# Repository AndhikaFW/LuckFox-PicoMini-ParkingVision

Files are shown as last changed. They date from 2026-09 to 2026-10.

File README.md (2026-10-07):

# LuckFox-PicoMini-ParkingVision

A distributed smart parking monitoring vision system utilizing **LuckFox Pico Mini** AI camera boards paired with **ESP32-S3 RAP** nodes, chained together and bridged to a Raspberry Pi 4 backend over wired Ethernet.

Every node in this project is a **parking lot** -- there is no separate entrance/gate node yet (may be added later as its own thing).

---

## System Components (per node)

Each parking-lot node is one **LuckFox Pico Mini** + one **ESP32-S3**, wired together over SPI:

1. **LuckFox Pico Mini (RV1103) -- on-device vision AI**
   - Reads a camera feed, encodes/splits it into **3x 600x400 video streams**.
   - Pipeline per stream: motion detection -> AI car detection -> sleep briefly -> occupancy check (vacant/occupied) -> if occupied, crop + OCR the plate.
   - Sends the 3 encoded video streams and, if present, the cropped plate result to its paired ESP32-S3.

2. **ESP32-S3 RAP (chain relay + one Gateway uplink)**
   - Runs the exact same firmware on every unit (see [`src/ESP32-S3-RAP`](src/ESP32-S3-RAP)); role and chain position come from a small per-unit provisioning step, not a separate build.
   - One designated node (`node_id == 0`, the **Gateway**) also carries a **W5500** module and bridges to the Raspberry Pi 4 backend over a direct Ethernet cable (RJ45) -- it's still a parking-lot node like any other, just the one with this extra uplink role.

---

## Network Architecture: Chain (not a closed ring)

Despite the "RAP" (Ring Access Protocol) name -- kept from this project's original design for naming continuity (`ring_size`, `node_id`, etc. still appear throughout) -- the topology is a **one-way chain**, not a closed loop: there's no "first" node and the Gateway has no outgoing link back into the chain, it only sinks data out to the RPi4.

Every node has its own initiative: it originates its own occupancy/plate reading and video frames on its own schedule, and relays whatever it receives from its upstream neighbor (`prev`) toward its downstream neighbor (`next`) -- both interleaved through the same per-hop link. Two independent transports run in parallel over the same radio:

- **ESP-NOW** -- small `StatusPacket`s (`origin_node_id`, `seq`, `occupied`, `plate`), hop-by-hop with stop-and-wait flow control (a node only accepts a new packet from `prev` once it has room to forward it to `next`).
- **WiFi AP+STA daisy-chain (TCP)** -- bulk video, since raw frames are far too large for ESP-NOW's 250-byte limit. Each frame carries `{origin_node_id, stream_id, seq, data_len}` so its source lot and camera are always identifiable, even after several relay hops.

```mermaid
graph LR
    subgraph "Chain Network (one-way, no closing loop)"
        Node1["Lot 1<br>(LuckFox + ESP32-S3)"] -->|"status/plate + video"| Node2["Lot 2<br>(LuckFox + ESP32-S3)"]
        Node2 -->|"status/plate + video"| Node3["Lot 3<br>(LuckFox + ESP32-S3)"]
        Node3 -->|"status/plate + video"| NodeN["... Lot N-1"]
        NodeN -->|"status/plate + video"| Gateway["Lot 0 / GATEWAY<br>(LuckFox + ESP32-S3 + W5500)"]
    end

    Gateway -->|"RJ45 (W5500), status:5000 video:5300"| RPi["Raspberry Pi 4 backend"]
```

### Why a chain instead of a mesh/star

- **Deterministic, low-collision flow**: every hop is a simple point-to-point link (ESP-NOW unicast + a WiFi AP/STA pair), so there's no contention/arbitration between nodes for a shared medium.
- **Backpressure, not packet loss**: per-hop stop-and-wait means a slow/busy hop naturally throttles the whole chain instead of dropping data silently.
- **Simple cabling-free daisy-chaining**: adding a lot just means provisioning one more node with the next `node_id`; no rewiring of a shared bus or router needed.

Self-healing/re-routing around a permanently dead node is **not** implemented yet -- see `docs/network/topology.md` in the submodule for the full list of current limitations.

---

## Data reaching the backend

Both channels tag every reading/frame with `origin_node_id`, so the Raspberry Pi 4 backend can always tell which lot (and, for video, which of its 3 cameras) a piece of data came from:

| Channel | Port | Content |
| :--- | :--- | :--- |
| Status/plate | 5000 | One line per reading: `node_id:occupied:plate` |
| Video | 5300 | Binary, one frame per message: `{origin_node_id, stream_id, seq, data_len}` + raw frame bytes |

Naming a lot (e.g. "Lot A0") is a Raspberry Pi-side concern, not firmware: see [`backend/node_names.json`](backend/node_names.json) and the demo listener scripts in the same folder (`status_listener.py`, `video_listener.py`), which resolve `node_id -> name` and prove data is separable/displayable per lot. This `backend/` folder is plain Python living directly in this repo (not the ESP32 firmware submodule, and not a submodule itself) -- it's Raspberry Pi-side code, kept separate from the ESP32-S3 firmware.

---

## Getting Started

### Cloning the Repository
```bash
git clone --recurse-submodules https://github.com/AndhikaFW/LuckFox-PicoMini-ParkingVision.git
```

If already cloned without submodules:
```bash
git submodule update --init --recursive
```

### Layout

- [`src/ESP32-S3-RAP`](src/ESP32-S3-RAP) -- ESP32-S3 firmware **only** (its own git submodule/repo). Build/flash/provisioning instructions and the full protocol/topology write-up live there: [`docs/network/topology.md`](src/ESP32-S3-RAP/docs/network/topology.md).
- [`backend/`](backend) -- Raspberry Pi 4-side Python (demo listeners + `node_names.json`). Plain files in this repo, not inside the firmware submodule and not a submodule of its own -- there's nothing here that needs its own version history separate from the rest of this repo.

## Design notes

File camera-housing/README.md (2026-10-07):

# Camera body + manual pan/tilt hinge (per parking-lot node)

One integrated camera body (LuckFox RAP Shield PCB + SC3336 module both INSIDE it) on a
manual 2-axis (pan + tilt) hinge, futuristic-minimalist styling. Four scripts:

- **`build_housing.py`** -- flat `Base` + `Standoffs` (a plain, non-pivoting PCB mounting
  plate). No longer used by the camera design below; kept because it's still a valid,
  independently-printable option if a flat non-pivoting mount is ever wanted, and because
  `camera_casing.py` imports the PCB/SC3336 dimension constants from it.
- **`camera_casing.py`** -- the actual camera design: `CeilingMount` (fixed) +
  `ComponentBox` (round, ROTATING turret -- placeholder enclosure for a future buck
  converter + W5500 module, also carries the pan/tilt arms) + `CameraBody` (the shell, PCB
  + SC3336 both inside, square-cross-section tube) + `BackCover` (removable, for
  PCB/heatsink access).
- **`assemble_pcb.py`** -- adds the real PCB (STEP import) onto `build_housing.py`'s Base,
  into `camera_housing.FCStd`. Only relevant if that flat mount is actually used.
- **`full_assembly.py`** -- combines `camera_casing.py`'s parts with the real PCB (STEP
  import, positioned inside `CameraBody`) into one `full_assembly.FCStd`.
- **`render_hero.py`** -- renders a genuine angled 3D shot (`hero_render.png`) from
  `full_assembly.FCStd`, working around the offscreen top-down-only bug the older render
  scripts hit (see "Regenerating everything" below for the actual root cause found).

## Regenerating everything

```bash
cd camera-housing
QT_QPA_PLATFORM=offscreen ~/Downloads/FreeCAD-1.1.3.AppImage --console <<'EOF'
exec(open('camera_casing.py').read())
EOF
QT_QPA_PLATFORM=offscreen ~/Downloads/FreeCAD-1.1.3.AppImage --console <<'EOF'
exec(open('full_assembly.py').read())
EOF
```
(`build_housing.py`/`assemble_pcb.py` only needed if you also want the standalone flat
mount -- see their own section below.)

The older renders (`render_casing.py`, `render_full.py`, `render_screenshot.py`) each
produce a `.png` from their matching `.FCStd`, but all render a straight-down top view
regardless of the `viewIsometric()` call in the script. **Root cause found**: inspecting
`view.getCamera()` right after `viewIsometric()` shows the camera's orientation is left at
identity (axis-angle `angle=0`) in this offscreen setup -- `viewIsometric()` silently fails
to actually rotate the camera here, even though it doesn't raise an error. `render_hero.py`
works around this by building and setting a real camera string directly (`view.setCamera(...)`
with a manually-computed non-identity orientation) instead of relying on `viewIsometric()`
-- confirmed via `getCamera()` showing a proper non-zero angle afterward, and the resulting
image actually being a real angled view, not another flat top-down one. Geometry
correctness in this project is still verified via real bounding-box/circle-center/
boolean-overlap queries first and foremost (see each section below for what was actually
checked) -- `render_hero.py` is for producing an actual presentable image, not for
verification.

(`--console camera_casing.py` as a direct CLI arg does *not* auto-run it in FreeCAD 1.1.3
-- pipe the `exec(...)` line into stdin as shown, or open the files as macros from the GUI.)

---

## The camera design (`camera_casing.py` + `full_assembly.py`)

### Why the PCB moved inside

Earlier revisions kept the PCB on a separate flat `Base`, cabled to a small external
camera head, specifically so heatsink work on the LuckFox Pico Mini never had to touch
the pan/tilt mechanics. On request, the PCB now lives inside `CameraBody` instead -- one
integrated unit, no external FPC run. Heatsink/PCB access is still separable: remove only
`BackCover` (a few M3 self-tap screws), the rest of the rig stays untouched.

### Hardware: M5 wing bolt (pan + left tilt), M4 set-screw (right tilt only)

M5 bumped up from M4 (used in the small SC3336-only version) now that the body is much
bigger/heavier -- it holds the full PCB, not just a 20x20mm sensor board. Only the right
tilt pivot uses an M4 self-tap set-screw instead of a wing bolt, since that's the only
bore that has to stay open end-to-end for the cable (see "Cable path" below) -- the pan
pivot is a plain M5 bolt like the left tilt one. Confirmed real, commonly stocked
(searched on Tokopedia, not guessed): "WING NUT M4 M5 M6 M8 M10 ... MUR KUPING MUR KUPU
KUPU" lists M4/M5 together.

### Assembly stack

**ComponentBox is now a round, ROTATING turret** (on request: "rubah kotak diatas kamera
... menjadi tabung bundar supaya dapat berputar"), replacing the old MountPlate<->PanPlate
pivot pair. Before implementing, the ambiguity in "supaya dapat berputar" (just reshape it
into a cylinder while keeping it fixed, vs. make ComponentBox itself the rotating part) was
checked directly with the user -- confirmed: ComponentBox itself rotates. This merges what
used to be three parts (a fixed square ComponentBox holding electronics + a fixed
MountPlate lid + a rotating PanPlate holding the arms) into two:

1. **CeilingMount** -- NEW, FIXED, sits at the bottom of the stack (wherever this gets
   mounted -- wall, pole, an off-the-shelf adjustable CCTV bracket, confirmed real listings
   exist, e.g. "Adjustable Bracket Tiang Kamera CCTV" on Tokopedia). Takes over MountPlate's
   old role but simpler: a plain M5 pan-pivot hole + 4 corner mounting holes, nothing else
   -- **no cable hole anymore** (the electronics moved onto the rotating ComponentBox
   itself, see "Cable path" below).
2. **ComponentBox** -- now a round, CLOSED cylindrical turret (`TURRET_D` diameter,
   `TURRET_H` tall) that ROTATES on top of CeilingMount via a plain M5 wing bolt + wing nut
   through both their centers (pan = left/right) -- same friction-lock hardware as every
   other pivot here. Meant to eventually hold a buck converter + W5500 Ethernet module (no
   standoffs/mounting holes for those two designed yet -- explicitly out of scope for now,
   see "What's NOT done yet"). The two side arms are now fused DIRECTLY to its own top
   face, **identical in thickness and width** (`ARM_T`/`ARM_W`, on request -- see
   "Symmetric arms" below) -- left has a plain M5 hole; right carries the **stationary
   spigot** (not CameraBody, see "Tilt hinge" below) + a hidden downward cable channel.
   ComponentBox's own pivot hole is on its BOTTOM face (mates with CeilingMount below);
   the arms are on the TOP face -- deliberately opposite faces so the two can't collide
   (checked, not assumed -- see "Cable path" below for the verification).
3. **CameraBody** -- the camera shell, a **square-cross-section tube** (`CASING_W` ==
   `CASING_H`, see "CameraBody dimensions" below). PCB standoffs (bought M3 hex spacers,
   fused in-place) behind an SC3336 mounting zone up front behind the lens; both fully
   enclosed, no external FPC needed since that ribbon run stays entirely inside this one
   cavity. Left side: solid pivot disc (M5 bolt). Right side: same-diameter disc with a
   bushing hole that the arm's spigot inserts into -- CameraBody is what rotates here
   (**tilt**, a separate axis from ComponentBox's own **pan** rotation). Open back.
4. **BackCover** -- separate part, plugs CameraBody's open back (skirt inserts into the
   cavity, 4 corner M3 self-tap screws through the cap). Remove only this for PCB access.

### Cable path: fully enclosed, one wall-hop into ComponentBox's own interior

The cable is for a **W5500 Ethernet module + a buck converter** that will eventually live
INSIDE **ComponentBox** itself (see "Assembly stack" above -- the electronics box and the
arm-holder are now the same rotating part). On request, it must never be open/exposed to
outside air anywhere along its run, and it must never have to exit any side face to reach
the box externally -- the pan pivot stays a plain solid bolt (it does not carry the cable),
so instead of crossing the pan joint coaxially, the cable stays entirely inside the right
arm and ComponentBox's own top wall:

1. Starts inside CameraBody (~3mm from the PCB's edge), through the **stationary spigot's**
   bore (see "Tilt hinge" below for why it's on the arm, not CameraBody).
2. One continuous bore carries it through the spigot AND partway into the arm's own body --
   just far enough to reach the down-channel (item 3), NOT all the way out to the arm's own
   outer face (see "Real bug caught" below).
3. Turns straight down through a hidden vertical channel (`DOWN_CHANNEL_D`, 10mm) inside
   the arm, continuing straight through ComponentBox's own top wall (`WALL_T`, 3mm) --
   **one wall-hop now, not two** (an earlier revision, before ComponentBox became the
   rotating turret, had this cross the arm's own plate AND a separate matching hole
   through a fixed MountPlate below it; now that the arms are fused directly onto
   ComponentBox's own body, there's no second plate to hop through anymore).
4. Arrives directly inside **ComponentBox**'s hollow interior -- the actual electronics
   destination, not a separate box one layer further down.

**CeilingMount has no cable hole at all** -- unlike the intermediate revision described
above (where a fixed MountPlate needed a hole reversing an earlier "no hole" rule), the
electronics moved onto the rotating ComponentBox itself, so there's nothing left for a
cable to reach past CeilingMount. It's back to a plain plate with just the pivot + 4
mounting holes.

**Real limitation, stated plainly, and already accepted**: this channel is off-center (at
the arm's own position, not the pan axis), so it only stays sensibly positioned relative to
ComponentBox's interior across a **limited pan range** -- rotating ComponentBox very far
swings the channel's exit point away from wherever the modules eventually get mounted
inside it. This is a deliberate tradeoff for keeping the pan pivot solid (not hollow), and
it does NOT apply to the tilt side -- see "Tilt hinge" below for why that one has no such
limitation.

**Checked, not assumed**: a probe run down through the arm's channel and ComponentBox's own
top wall confirmed the path is genuinely open at every height sampled (`pivot_z`,
`TURRET_H`, `TURRET_H - WALL_T`, and just past it into the hollow interior), and a separate
point deep inside ComponentBox's own interior confirmed it's genuinely hollow (not
accidentally solid). ComponentBox's pivot hole and CeilingMount's pivot hole were also
confirmed to land on the exact same X/Y (needed for the bolt to actually pass through
both) -- and the whole turret (body + both arms + spigot) was confirmed to be ONE connected
solid (`Solids` count == 1), not a floating, disconnected arm that only LOOKED fused on
screen.

**Went through several attempts before landing here** (each corrected after being told
what was actually meant, not guessed again):
1. An off-axis extra hole next to the tilt's M5 bolt, reusing that hardware unmodified --
   rejected, the cable needs to go through the *inside* of the hinge, not next to it.
2. Fixed the tilt hinge to be truly coaxial, but left the pan pivot a solid M5 bolt --
   still blocked one joint further down. Made the pan pivot hollow too.
3. Made the pan shaft's bore continue down through MountPlate and exit via a hole in its
   back edge, assuming the cable needed to reach some external point beyond MountPlate --
   wrong assumption (the destination modules sit ON MountPlate's deck, not beyond it).
4. The hollow pan shaft itself turned out to be unwanted, not just its exit hole -- the
   cable only needed to travel through the arm, not through the pan pivot at all. Reverted
   the pan pivot to a plain solid bolt and moved the path into a hidden channel inside
   PanPlate's own body instead.
5. That channel (10mm) was cut through an arm only 6mm thick -- it broke straight through
   the arm's front and back faces, a visible stray hole. Widened the right arm to 14mm
   specifically so the channel stays fully enclosed with wall margin on both faces -- and
   separately, moved the hollow tube from CameraBody to the arm (also this round), since
   the tube being on the ROTATING part is what limited the earlier tilt design to a partial
   angle range in the first place.
6. That tube's own receiving boss on CameraBody had to grow (~22mm) just to contain its
   bushing hole, while the left boss stayed 16mm -- functionally fine, but the size
   mismatch looked like an odd separate "big tube" bolted onto only one side. Fixed by
   unifying both discs to one `HINGE_DISC_OD` and decoupling the spigot's length from the
   cable bore's, so the spigot could shrink back down to a short alignment pin instead of a
   long tube.
7. Once `ComponentBox` was added below MountPlate as the actual electronics enclosure, the
   cable path still stopped at MountPlate's top deck -- which would have meant routing it
   externally along the outside of the box to actually reach the modules inside, exactly
   the "kabel keluar samping" the design was supposed to avoid. Fixed (the current design,
   above) by extending the same channel through a matching hole in MountPlate, reversing
   the earlier "no hole in MountPlate" rule now that the real destination moved below it.
8. **Real bug caught** ("kenapa di lengan yang ada jalur kabel ada lobang besar di bagian
   luar lengan"): the horizontal bore connecting the spigot's bore to the down-channel used
   to start 1mm PAST the arm's own outer (far, away-from-CameraBody) face and cut inward
   through the whole `ARM_T` thickness -- which meant the entire arm got drilled straight
   through to its exposed outer side, an open hole with no purpose (the bore only actually
   needs to reach `channel_x`, in the middle of the arm, to connect with the down-channel;
   it never needed to reach the outer face at all -- there's no drilling-access reason to,
   since this is 3D printed as one piece). Fixed by starting the cut at `channel_x + 1mm`
   instead, a blind bore that stops inside the arm. Checked, not assumed: probed the arm's
   own outer face at the pivot's Y/Z after the fix -- now solid (`isInside()` == True) right
   up to the true outer face, and a separate probe confirmed the horizontal bore still
   connects cleanly to the down-channel (both share the same Y center, so reaching
   `channel_x` is enough -- no isthmus of material left between them) and the full path
   from inside CameraBody down into ComponentBox is still completely open.
9. **Topology change**, on request ("rubah kotak diatas kamera ... menjadi tabung bundar
   supaya dapat berputar"): ComponentBox reshaped from a fixed square box into a round,
   ROTATING turret, absorbing PanPlate's old arm-holding role. This was explicitly
   clarified before building -- two readings were possible ("just make it round, keep it
   fixed" vs. "make ComponentBox itself the rotating part"), the user confirmed the
   latter. The old MountPlate<->PanPlate pivot pair is gone; CeilingMount (new, fixed,
   simpler than the old MountPlate since it carries no cable hole anymore) now pivots
   directly against the rotating ComponentBox. This also shortened the cable path from two
   plate-hops (arm+PanPlate, then a separate MountPlate hole) down to one (arm, then
   straight through ComponentBox's own top wall) -- see the walkthrough above.

### Tilt hinge (left/right, not a bottom tab) -- DJI Osmo Pocket-style matching discs

**Current design**: the two tilt pivots are mechanically different, and which side holds
the spigot matters -- but both now show the SAME `HINGE_DISC_OD` (24mm) disc on
CameraBody, styled after DJI Osmo Pocket's gimbal (flush matching pivot housings, not a
small boss on one side and a noticeably bigger one on the other).
- **Left** (`HINGE_DISC_OD`, solid): a normal M5 wing bolt + wing nut through CameraBody's
  disc and ComponentBox's arm -- this is the structural/load-bearing side.
- **Right** (`HINGE_DISC_OD` disc on CameraBody / `SPIGOT_OD` spigot on the arm): the arm
  (fixed to ComponentBox, doesn't tilt -- only CameraBody does) has a SHORT spigot --
  stationary relative to tilt, printed as one piece with ComponentBox -- that crosses
  `PIVOT_GAP` and engages
  `SPIGOT_LEN` into CameraBody's disc, just enough for real rotational support (it does
  NOT reach all the way to the wall/interior -- that's the cable bore's job, cut
  separately and independently, see "Cable path" above). CameraBody's disc has a bushing
  hole (not a bolt hole -- it has to stay open for the cable) that receives the spigot and
  rotates around it, so there's no wing nut on this side. A radial M4 self-tap set-screw,
  drilled through **CameraBody's disc** (the ROTATING part now), presses inward on the
  stationary spigot for friction-lock (loosen to retilt, tighten to hold).

Putting the spigot on the STATIONARY arm (not CameraBody) is what lets the down-channel
below stay connected at ANY tilt angle -- an earlier revision had it on CameraBody (the
ROTATING side) instead, which only stayed aligned across a limited angle, since a hole on
a rotating part sweeps around as it turns.

No custom hollow bolts, no bearings -- the spigot is just a short printed shaft, part of
ComponentBox's arm itself, and everything else is the same M4/M5 hardware used throughout.

**Two real things caught and fixed here, not just design choices**:
1. CameraBody's right boss initially reused a smaller diameter (16mm, matching the left
   boss) -- but the bushing hole through it needs to fit the shaft (~16.4mm with
   clearance), which is *bigger* than a 16mm boss. Cutting a 16.4mm hole through a
   16mm-diameter boss removes the entire boss -- checked, not assumed: CameraBody's
   measured width matched exactly what you'd get with the right boss totally absent (a
   flush wall, no protrusion at all). First fixed by growing just the right boss (~22mm) --
   which then became its own complaint ("why is there a big tube on just one side") --
   resolved properly by unifying BOTH sides to the same `HINGE_DISC_OD` (24mm), on request
   ("skema DJI Osmo Pocket").
2. The body-to-hinge reach kept creeping up across these fixes (10mm boss -> 22mm boss ->
   a long separate tube). Reset by decoupling the spigot's length (short, `SPIGOT_LEN`,
   just for mechanical engagement) from the cable bore's length (longer, cut
   independently, reaches wherever the cable actually needs to go) -- the spigot no longer
   has to be as long as the whole cable path, so it doesn't need to look like a stalk.

**Retention caveat, stated plainly**: the spigot is *not* positively retained against
CameraBody sliding back off it -- only friction (the set-screw, and the left bolt holding
the body's attitude fixed) keeps it seated. A flanged/captured version was considered and
dropped: the flange would need to be bigger than CameraBody's hole to retain it, which
makes it physically impossible to assemble (can't push a bigger flange through a smaller
hole) since the spigot+arm print as one piece. Fine for a first build; a dab of glue or a
zip-tie at that joint is a reasonable belt-and-suspenders addition if wanted.

**Both pivots must be coaxial** (same Y/Z axis) for the body to tilt cleanly without
binding -- this constrains the spigot's height to `TILT_LOCAL_Z`, the same as the left
pivot, which sits close to the PCB's own height. Checked, not assumed: CameraBody's actual
bushing hole (scoped to just the wall + disc length, not a full-width sweep) has exactly
**0mm³ overlap** with the PCB -- the PCB's own solid extent stops about 3mm short of the
wall, so the cable crosses that small open-air gap to reach the board's edge, then routes
by hand within the `COMPONENT_CLEARANCE` headroom to reach the connector (not itself
routed through any additionally-modeled channel -- a manual assembly detail).

**Verified via real geometry queries (not assumed)**, printed by `camera_casing.py` and
`full_assembly.py` themselves, plus ad-hoc probes during this revision:
- CeilingMount/ComponentBox, ComponentBox/CameraBody, CameraBody/BackCover: exactly 0mm³
  solid overlap (no collision).
- **Both of CameraBody's discs (left and right) measured at the exact same radius
  (12.0mm = `HINGE_DISC_OD`/2)** -- confirmed by reading circle centers straight out of
  the geometry, not just trusting that the formula was applied on both sides.
- Left M5 hole (both parts), and the spigot/bushing pair (arm's spigot OD, CameraBody's
  bushing hole), all share the exact same Y/Z axis line.
- The set-screw pilot (on CameraBody now) is confirmed to actually reach the spigot's
  outer surface -- probed at its expected end point, 0mm³ (open, as a drilled hole should
  be).
- CeilingMount is confirmed solid everywhere except its 4 corner mounting holes and central
  M5 pivot hole -- no cable hole at all anymore (the electronics moved onto ComponentBox,
  see "Cable path" above).
- ComponentBox's own pivot hole (bottom face) and CeilingMount's pivot hole are confirmed
  to land on the exact same X/Y (needed for the bolt to actually pass through both, not
  just look aligned from above).
- The whole ComponentBox turret (cylinder body + both arms + the spigot) is confirmed to be
  **ONE connected solid** (`Solids` count == 1) -- not a disconnected, floating arm that
  only looked fused in a still image.
- The arm's hidden down-channel, and its continuation straight through ComponentBox's own
  top wall into its hollow interior, are confirmed genuinely open the whole way -- probed
  at `pivot_z`, `TURRET_H`, `TURRET_H - WALL_T`, and just past it: all open, and a separate
  point deep inside the turret confirmed genuinely hollow (not accidentally solid). The
  channel is also still fully enclosed within `ARM_T` (shared by both arms, see "Symmetric
  arms" above), with a solid 2mm margin probed on both the arm's front and back faces (the
  "hole not visible" fix, still holding after this revision).
- **Bushing hole / PCB overlap: 0mm³**, and still exactly 3mm of open-air gap from the
  bore's inner reach to the PCB's edge -- unchanged after shortening the spigot, since the
  cable bore's own length is computed independently of the spigot's shorter one.
- BackCover's skirt actually nests inside CameraBody's open cavity (Y-ranges overlap,
  confirmed by bounding box) rather than just butting up against the opening -- an earlier
  version had the skirt pointing the wrong way (out, not in), also caught by this check.
- **BackCover/CameraBody overlap: 0mm³** (was ~3mm³, a sliver at the fillet corners, in an
  earlier revision -- fixed by giving `CASING_DEPTH` its own explicit term for
  `COVER_SKIRT_DEPTH` + `COVER_BACK_CLEARANCE` instead of reusing `MARGIN` alone, which
  used to be thinner (5mm) than the skirt itself (6mm) and let it clip into the PCB's back
  edge -- the original bug report that started this round of fixes).
- The real PCB (STEP import) bounding box is **fully contained inside** CameraBody's
  bounding box, and PCB/CameraBody solid overlap is exactly 0mm³.

### Body-to-hinge distance: tightened twice

**First pass** ("jarak body ke engsel terlalu jauh"): the old `SIDE_BOSS_LEN` 10mm -> 6mm
and `PIVOT_GAP` 1mm -> 0.5mm, shrinking the standoff from 11mm to 6.5mm. `PLATE_SIZE` was
reduced to match (95mm -> 88mm).

**Second pass**, as part of the Osmo Pocket disc-unification above: decoupling the
spigot's length from the cable bore's length meant the spigot only needs `SPIGOT_LEN`
(4mm) of real engagement, not a long reach all the way to the wall -- CameraBody's own
width shrank further as a direct result (69mm total for both discs, down from 73mm with
the old 6mm-boss-each-side version, itself down from the original 81mm).

Re-verified after each change, not assumed still valid: all the same checks above still
pass (0mm³ overlaps throughout, coaxial pivots, PCB clearance still exactly 3mm, the
hidden channel still has solid material on both of the arm's faces) -- shortening the
reach didn't quietly reopen any of the earlier bugs.

`HINGE_DISC_LEN`/`PIVOT_GAP`/`SPIGOT_LEN` weren't shrunk to zero: some length is still
needed for the disc to actually behave like a bearing surface (not just a thin wafer), for
an M5 wing nut to have room to be tightened by hand without hitting the wall, and for the
spigot to provide real rotational support rather than wobble. Current values are
tightened-but-functional, not proof of the true minimum -- there's likely still a bit more
room to shrink if that's ever wanted, just untested past this point.

**Note**: the plate/footprint size grew back up in a later pass ("Symmetric arms" below,
both arms widened to match), and then the whole footprint concept changed again when
ComponentBox became a round turret (`TURRET_D`) -- neither is a regression of this
tightening pass, just separate later changes layered on top.

### Symmetric arms

On request ("buat kedua lengan sama dimensinya dan tidak keluar area kotak"), both side
arms share the exact same `ARM_T` (thickness, X direction) and `ARM_W` (width, Y direction)
-- previously the left arm stayed slim (6mm) since it never needed the down-channel's
enclosure margin, while only the right arm was widened to 14mm for that reason (see "Cable
path" above). Unifying both to the wider value is what was asked for; nothing shrank below
what the channel actually needs.

This footprint constraint applied to the OLD square `ComponentBox`/`PanPlate` design (a
fixed `PLATE_SIZE`, derived so both arms stayed fully inside a square plate). Now that
`ComponentBox` is a round rotating turret (see "Assembly stack" above), that specific
"stay inside a square" requirement no longer applies -- `TURRET_D` (110mm) just needs to be
big enough that the arms genuinely overlap/fuse onto the turret's own top face, not that
they stay fully inside its circular silhouette (checked directly: the whole turret + both
arms + the spigot measured as ONE connected solid, `Solids` count == 1 -- not a
disconnected floating arm that only looked attached on screen).

### CameraBody dimensions

`CASING_W` is driven by the real, CONFIRMED PCB size (not guessed): `PCB_W` + 2×`MARGIN` +
2×`WALL_T` ≈ 61mm -- a real physical constraint, not a styling choice; a body enclosing a
45x63mm PCB cannot be a small compact camera, whatever the styling. `CASING_DEPTH` =
`WALL_T` + `CAM_MODULE_DEPTH` + `PCB_H` + `MARGIN` ≈ 86mm.

`CASING_H` is now set equal to `CASING_W` (≈61mm), on request -- CameraBody reads as a
**square-cross-section tube** ("tabung persegi"), not the flatter ~41mm-tall rectangular
box earlier revisions used. Since `CASING_W` can't shrink (real PCB constraint above),
`CASING_H` had to grow to match it rather than the other way around. The PCB/component
stack itself only actually needs `_CASING_H_MIN` = `STANDOFF_H` + `PCB_T` +
`COMPONENT_CLEARANCE` + 2×`WALL_T` ≈ 41mm -- `camera_casing.py` asserts `CASING_H >=
_CASING_H_MIN` at import time so this can never quietly regress into a too-short body; the
extra ~20mm of height versus the old design is genuinely spare interior, not needed for
fit. Rounded/filleted vertical edges (`FILLET_R`) and a recessed circular bezel ring around
the lens are the "futuristic minimalist" styling cues, same as the earlier SC3336-only
design.

**Assumed** (search `camera_casing.py` for "ASSUMED"): `COMPONENT_CLEARANCE` (18mm --
tallest stack above the PCB, e.g. ESP32 Dev Board Breakout on pin headers, not measured
against the real populated board); `CAM_MODULE_DEPTH` (15mm -- front cavity for the
SC3336 board + lens holder). SC3336/lens dimensions (`CAM_BOARD_W/H`, `CAM_MOUNT_HOLE_D`,
`CAM_MOUNT_SPACING`, `LENS_HOLE_D`) and PCB dimensions (CONFIRMED, from the real
`.kicad_pcb`) both come from `build_housing.py` -- one place per number, not duplicated.

### Styling pass: rounded edges everywhere a mating surface doesn't need to stay flat

On request ("buat desain supaya lebih menarik untuk dilihat"), extended the rounding
beyond just the 4 vertical corners (`fillet_vertical_edges()`, used throughout since the
first revision) to more edges on most parts:

- `fillet_vertical_and_cap_edges(shape, radius, cap_axis, cap_value)` -- rounds the 4
  vertical edges PLUS the 2 horizontal edges of ONE chosen face, leaving the opposite face
  sharp. **CameraBody**: front cap (`cap_axis="y", cap_value=0`, the lens face) is rounded
  into a "capsule" profile, blending into the same rounded vertical corners used all along
  its depth. The BACK stays sharp on purpose -- BackCover's flat skirt needs a flat
  rectangular opening to nest into (see "Assembly stack"); rounding the back too would need
  BackCover's own skirt profile to match, which isn't done here.
- Both arm posts (`fillet_vertical_edges()`, applied to each arm's own box before the
  spigot/holes are cut in) have rounded vertical corners too, matching the hinge discs'
  rounded look instead of being plain sharp-edged rectangular blocks.

**Two real OCC fillet failures caught here, both by checking the actual result instead of
trusting that the fillet call succeeded:**
1. Tried rounding ALL 12 edges of MountPlate/PanPlate's own flat plates at once (vertical +
   top perimeter + bottom perimeter). OCC's fillet needs a full 3-way corner blend at all 8
   box vertices when all 12 edges are selected together, and it threw
   `Part.OCCError: BRep_API: command not done` on that plate's proportions (thin relative
   to its footprint). Reverted to `fillet_vertical_edges()` (the proven approach) rather
   than force a fragile operation. (Those two parts don't exist anymore after the
   ComponentBox topology change below, but the lesson -- full-loop/multi-edge box fillets
   are fragile -- carried forward.)
2. Tried rounding ComponentBox's round top rim (a single, full 360-degree circular edge)
   when it became a cylinder. This one didn't error out -- it silently produced a WRONG
   result: instead of rounding the rim inward like a normal edge fillet, OCC ballooned the
   whole cylinder's radius outward. Caught by checking bbox before/after: a plain
   unfilleted `TURRET_D`=110mm cylinder measured X 0..110 as expected, but after the fillet
   call the SAME cylinder measured X -4.53..114.53 -- a real ~4.5mm radius INCREASE, not a
   rounded corner. Left the turret's rims sharp/unfilleted rather than ship a shape quietly
   bigger than its own stated diameter.

**Checked, not assumed**: re-ran the full build from scratch after both fixes --
succeeded cleanly with no errors, and `full_assembly.py`'s full overlap/PCB-containment
suite still passed unchanged (all 0mm³, PCB still fully inside CameraBody, 3mm clearance
gap unchanged). Also directly probed CameraBody's own front-top-left corner with
`isInside()` along a 45-degree sweep from the fillet arc's own center: solid out to ~2.6mm,
empty from 3.0mm onward -- confirming a genuinely rounded ~2.5mm (`FILLET_R`) arc is really
there, not just a fillet call that silently no-op'd. (Offscreen FreeCAD renders still only
show a flat top-down view regardless of camera angle -- see "Regenerating everything" above
-- so this numeric probe stood in for eyeballing a render.)

### ComponentBox: round rotating turret, placeholder enclosure for the buck converter + W5500 module

`ComponentBox` (`build_component_box_with_arms()`) is a round, closed cylinder --
`TURRET_D` (110mm) diameter, `TURRET_H` (25mm) tall -- that ROTATES on top of the new fixed
`CeilingMount` (see "Assembly stack" above for the full topology change). It's deliberately
minimal inside: hollow, closed top + bottom + side walls (own `WALL_T` walls, same as
CameraBody's shell), no standoffs or mounting holes for the buck converter/W5500 module
modeled yet -- on request ("tidak perlu dibuat dudukan untuk sekarang"), it's just an empty
enclosure for those. The cable itself, however, already reaches all the way inside (see
"Cable path" above).

`TURRET_D` (110mm) is a placeholder, but sized off REAL searched component dimensions
rather than guessed outright: a common LM2596 buck converter module measures 43.2 x 21 x
14mm, and a W5500 Ethernet module with an RJ45 jack measures roughly 55 x 28 x 15mm. Both
fit comfortably within a 110mm circle side by side, and `TURRET_H`'s 25mm clears the taller
module (15mm) with real room left for wiring -- but exact placement, orientation, and
mounting for either module still isn't designed (see "What's NOT done yet"). Unlike the old
square box, `TURRET_D` no longer has to satisfy an "arms must stay inside the footprint"
formula (see "Symmetric arms" above) -- it just needs to be big enough that the arms
genuinely fuse onto the turret's own top face, which is checked directly (turret + both
arms + spigot come out as ONE connected solid), not derived from a containment formula.

### What's NOT done yet

- **The buck converter + W5500 module themselves aren't designed** -- explicitly out of
  scope for now (on request). `ComponentBox` exists as an empty, round enclosure (see
  above) sized off real module dimensions, but has no standoffs or mounting holes yet. The
  cable path DOES now reach inside it (see "Cable path" above) -- what's missing is only
  where/how the two modules themselves physically mount once their real
  dimensions/orientation are decided.
- No weatherproofing anywhere along the cable path (the right tilt bushing joint, the
  hidden channel's crossing into ComponentBox's own top wall) or at BackCover's skirt fit
  -- worth real attention before outdoor use, since this is now also the water ingress
  path, not just a mechanical one. The new CeilingMount<->ComponentBox pan pivot is also
  unsealed.
- `CEILING_MOUNT_HOLE_D`/pattern on CeilingMount is generic -- match it to whatever
  pole/wall bracket actually gets bought.
- The right tilt shaft isn't positively retained in the arm's bushing bore -- relies on
  friction (its set-screw, plus the left M5 bolt keeping the body's attitude fixed). Fine
  for a first build; glue or a zip-tie at that joint is a reasonable addition if more
  security is wanted.
- Actual achievable tilt range isn't computed for the right (bushing) pivot -- being a
  true coaxial bushing, rotation itself isn't the limiter there; what would actually stop
  it at some angle is CameraBody's own corners swinging into ComponentBox. Pan range
  (ComponentBox on CeilingMount) is separately limited by the off-center cable channel
  losing alignment with ComponentBox's own interior (see "Cable path" above) -- neither
  has been swept/measured.
- Hasn't been checked against the LuckFox Pico Mini's actual heat output -- `CameraBody`
  is now a mostly-sealed box (BackCover screw holes and floor standoff pilot holes are the
  only openings to outside air, now that the cable path terminates inside the assembly
  instead of exiting anywhere), which may or may not be adequate passive cooling depending
  on real thermal load. Worth a real check before this goes in the field.

---

## `build_housing.py` + `assemble_pcb.py`: flat mounting plate (alternate, unused by the camera design above)

- **Base**: flat `FLOOR_T`-thick (2mm) plate, no walls, no camera geometry. 4x M3
  clearance through-holes at the real PCB mounting-hole positions. `build_base(ext_h=...)`
  takes an optional length override.
- **Standoffs**: reference/BOM part, not printed. Represents 4x off-the-shelf M3
  male-female hex spacers (confirmed real listing -- "Spacer Kuningan M3 Male Female",
  Prima Terang, Tokopedia -- stocked in 5/6/8/10/15/20/25/30mm) that hold the PCB above
  Base.

**Confirmed** (read directly from `../LuckFox-RAP-Shield-PCB/LuckFox RAP Shield.kicad_pcb`):
board outline 45.0022 x 63.2268mm, 1.6mm thick, 4x M3 mounting holes at
(4.0022,3.9) / (4.0022,59.3) / (41.0022,59.3) / (41.0022,3.9) relative to the board's
bottom-left corner.

`assemble_pcb.py` mirrors the imported STEP shape across the Y=0 plane before placing it
(KiCad's exporter converts screen-Y-down to world-Y-up) -- confirmed, not guessed, by
reading the 4 real M3 hole circle centers straight out of the STEP geometry: they land at
`(117,-78.9)` etc., exactly the KiCad absolute X/Y with Y negated. Mirroring back across
Y=0 recovers the exact raw KiCad coordinates that `MOUNT_HOLES` are defined against. The
same mirror/translate logic is reused in `full_assembly.py` for placing the PCB inside
CameraBody.

### History

This file used to build the camera mount too (first a full weatherproof enclosure with a
Lid + hinge, then a fixed `CameraPlate` behind a `Hood` recess, then nothing once
`camera_casing.py`'s external pan/tilt head took over). Now the PCB itself has also moved
into `camera_casing.py`'s `CameraBody`. See git log for any earlier version.

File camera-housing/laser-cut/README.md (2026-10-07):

# Casing VIPARK untuk laser cutting (aluminium + baja)

Pola datar (DXF) untuk casing kamera + kotak plafon. Semua angka ada di `make_laser_cut.py` (bagian parameter);
ubah lalu jalankan ulang:

```
pip install ezdxf shapely matplotlib rectpack
python3 make_laser_cut.py        # DXF, pratinjau, tabel komponen -> out/
python3 make_print_a4.py         # PDF cetak 1:1 di kertas A4      -> out/cetak_A4_1to1.pdf
```

| Folder / file | Isi |
|---|---|
| `out/dxf/` | **satu DXF per komponen**, kirim ini ke toko laser |
| `out/sheets/` | komponen yang sama ditata per bahan (aluminium 2 mm, baja 3 mm, akrilik 3 mm) |
| `out/png/` | pratinjau tiap pola datar |
| `out/cetak_A4_1to1.pdf` | **4 halaman A4, skala 1:1**, tiap bagian utuh (tidak dibelah) |
| `out/assembly.png` | tinjauan susunan 3D (kotak kasar, bukan geometri lipatan) |
| `out/parts_table.md` | tabel komponen, massa, dan semua pemeriksaan otomatis |

## Komponen

| Kode | Bagian | Bahan | Pola datar | Tekuk |
|---|---|---|---|---|
| A1 | wadah badan kamera: saluran depan + atas + bawah, flens belakang, sirip sisi | Al 2 mm | 87 × 250 | ya |
| A2 | tutup belakang kamera (4 baut M3 ke rivet nut di flens A1) | Al 2 mm | 68 × 44 | - |
| A3 | tutup jendela RF (tempel double-tape) | akrilik 3 mm | 44 × 71 | - |
| S1 / S2 | **plat sisi kiri / kanan** badan kamera (membawa poros ke lengan) | baja 3 mm | 94 × 44 | - |
| S3 / S4 | lengan kiri (slot kunci sudut) / kanan (jalur kabel), braket L | baja 3 mm | 97 × 36 | ya (1) |
| B1 | kotak plafon: tray 4 sisi + 2 flens, bukaan sisi di dinding +Y | Al 2 mm | 217 × 168 | ya |
| B2 | tutup kotak plafon dengan telinga angkur | Al 2 mm | 154 × 54 | - |

Plat port **belum dibuat**. Kotak `B1` hanya punya **bukaan 96 × 30 mm** dan **4 lubang rivet nut M3** untuk plat
**116 × 40 mm** (baut di x = ±53, z = ±9 dari pusat bukaan). Plat yang nanti Anda buat mengikuti pola itu
(parameter `PLATE_*`, `OPENING_*`), atau kirim ukuran papan W5500 dan buck, lalu bukaannya saya sesuaikan.

Ukuran: kamera 62 (+2×3 mm plat baja = 68) × 44 × 94 mm; kotak plafon 124 × 54 × 50 mm (lid dengan telinga 154 mm).
Massa kerangka ±606 g (aluminium 256 g, baja 339 g, akrilik 11 g).

## Kamera SC3336: yang perlu Anda ukur

Lubang baut papan kamera **belum dipotong**. Dokumen publik hanya menyebut papan **25 × 24 mm**, tebal total **18 mm** dengan
lensa. Dari foto produk: **3 lubang baut di sudut**, lensa **tidak di tengah papan**, dan cincin depan laras lensa ±17 mm.
Karena itu asumsi lama (4 lubang M2, jarak 14 mm, lubang lensa Ø10,5) salah.

Ukur dengan jangka sorong, lalu isi di `make_laser_cut.py`:

```
LENS_HOLE_D = 18.5        # sekarang perkiraan dari foto; ganti dengan Ø laras terlebar yang melewati plat + 0,5 mm
CAM_HOLES   = [(dx, dz), ...]   # pusat tiap lubang baut relatif terhadap SUMBU LENSA, dilihat dari DEPAN
                                # (dx ke kanan, dz ke atas), dalam mm. Contoh: [(-8.5, 7.5), (9.0, -9.5), (9.0, 8.0)]
CAM_HOLE_D  = 2.2         # diameter lubang baut (M2)
CAM_DEPTH   = 15.0        # kedalaman rongga di belakang plat depan (papan + kabel FFC + standoff)
```

Yang diukur: (1) diameter lubang tiap baut, (2) posisi tiap lubang dari sudut kiri-bawah papan, (3) posisi sumbu lensa dari
sudut yang sama, (4) diameter terbesar laras lensa yang harus lewat lubang, (5) berapa mm laras menonjol di depan papan.
Foto papan dari atas bersama penggaris juga cukup.

## Cara baca gambar / pesan ke toko laser

* Layer **CUT** = potong; **BEND** = garis lipat (tengah zona tekuk, **jangan dipotong**); **LABEL** = teks, abaikan.
* Pola datar digambar menghadap sisi **luar**; semua tekukan 90° **menjauhi** pembaca.
* Aluminium **5052-H32 tebal 2 mm**: r dalam 2 mm, K = 0,40, setback luar 4 mm. Baja lunak **3 mm**: r dalam 3 mm.
  Jika toko punya tabel tekuk sendiri, minta mereka hitung ulang dari **ukuran LUAR** (tertera di `parts_table.md`).
* Lubang rivet nut `Ø5,0` (M3) dan `Ø6,0` (M4) mengikuti nut umum: **cocokkan dengan nut yang Anda beli**.
* Baja: bebas gerinda lalu cat/powder-coat atau zinc (atau stainless 304 3 mm). Aluminium + baja aman di dalam ruangan.

## Cara kerja sambungan

* **Plat baja = sisi kamera.** A1 tidak punya dinding samping; ia saluran dengan 4 sirip pendek (16 mm) di sisi.
  Plat `S1`/`S2` dibaut ke sirip dengan 4 baut M3×10 + mur nyloc per sisi. Sirip berhenti di sekitar poros supaya mur
  poros muat; mur dipasang dari sisi yang masih terbuka sebelum plat kedua dipasang.
* **Kotak plafon**: lengan `S3`/`S4` dibaut ke dasar `B1` dengan rivet nut M4 (kaki lurus ke tengah). Tutup `B2` dibaut
  dari atas ke rivet nut M3 di flens `B1`, telinganya untuk angkur plafon M6.
* **Kabel** keluar dari ujung pipa berongga di poros kanan, berbelok naik lalu masuk grommet Ø10 di dasar kotak (S-curve
  14 mm, radius ±41 mm, dicek di skrip).

## Baut bos jalur kabel + cincin pengunci (sisi KANAN)

**Pilihan utama: pipa ulir berongga M10×1,0** (*lamp pipe nipple*, bahan lampu gantung).

| Spesifikasi | Nilai |
|---|---|
| Ulir | M10 × 1,0 (halus) |
| Lubang dalam | ±6,7 mm (6,5–7,0 tergantung pabrik) → kabel **maks Ø5 mm** |
| Panjang | **25 mm** (beli 30–50 mm lalu gergaji dan haluskan ujungnya) |
| Bahan | kuningan atau baja berlapis seng |
| Mur pengunci | M10×1,0 tebal 4 mm, **3 buah** (1 di dalam badan, 2 di luar lengan = cincin pengunci + mur jam) |
| Ring | 2× ring datar M10, 1× ring nilon/PTFE Ø10,5×Ø20×1 mm antara plat baja dan lengan |

Urutan dari dalam ke luar (dicek di skrip): `mur 4 · ring 1,5 · plat baja 3 · nilon 1 · lengan 3 · ring 1,5 · mur 4 · mur jam 4`.
Mur dalam mengunci pipa ke badan; mur luar mengatur gesekan sudut miring.

**Alternatif siap pakai: cable gland logam PG9 / M16×1,5** (badan gland = bos, mur gland = cincin pengunci + penjepit
kabel). Lubang pivot harus Ø16,2 mm: ubah `RIGHT_BOSS_HOLE = 16.2`. Kabel Ø4–8 mm.

**Peringatan kabel:** lubang 6,7 mm tidak bisa dilewati konektor header 8-pin. Lewatkan kabel tanpa konektor, lalu
crimp/solder setelah menembus, atau pakai konektor sempit (≤ 6 mm).

Kata kunci pencarian: *pipa ulir M10 lampu*, *hollow threaded rod M10x1*, *lamp pipe nipple M10*, *cable gland metal PG9*.
Referensi: [pipa ulir M10×1 berongga](https://www.mc-fact.eu/en/shop/lighting/lamp-threaded-nipple-m10-20mm/),
[PG9 / M16×1,5, lubang 15,5–16,3 mm](https://www.metalcablegland.com/metric-cable-gland/m16-metal-cable-gland/).
Stok marketplace lokal belum diperiksa.

## Sisi KIRI: baut biasa + kunci sudut

* Poros: baut **M6×25**, kepala di dalam badan (+ ring), ring nilon 1 mm, mur **nyloc M6** di luar lengan.
* Kunci sudut: baut **M5×20**, kepala di dalam, melewati **slot busur ±45°** di lengan `S3`, dikencangkan dengan
  **mur kupu-kupu M5**.

## Perangkat keras lain

| Untuk | Barang |
|---|---|
| Plat sisi ke sirip A1 (2 × 4) | 8× M3×10 + 8× mur nyloc M3 |
| PCB di lantai wadah | 4× standoff M3 **female-female 15 mm** + 4× M3×6 (dari bawah) + 4× M3×5 (atas) |
| Papan kamera SC3336 | standoff/baut M2 sesuai pola lubang yang Anda ukur |
| Tutup belakang `A2` | 4× rivet nut M3 di flens `A1` + 4× M3×6 |
| Kotak plafon | 4× rivet nut M3 + 4× M3×6 (tutup `B2`); 4× rivet nut M3 (plat port nanti); 4× rivet nut M4 + 4× M4×10 (lengan); grommet karet untuk lubang Ø10 |
| Plafon | 4× angkur M6 sesuai jenis plafon (lubang Ø6,5 di telinga `B2`) |
| Jendela RF | double-tape tipis / VHB untuk `A3` |

## Yang HARUS diperiksa sebelum memotong logam

1. **Antena WiFi/ESP-NOW.** Wadah aluminium meredam sinyal ESP32. Ada **jendela RF** 32 × 59 mm di dinding atas (di atas
   seluruh papan ESP32), ditutup akrilik `A3`. Dari diagram pin DevKitC-1, antena ada di ujung pin 3V3/RST (ujung depan
   di susunan ini). Ukur RSSI/packet loss antar-node **sebelum dan sesudah** casing ditutup.
2. **Lubang lensa dan baut SC3336**: lihat bagian di atas, harus diukur dari papan asli Anda.
3. **Dimensi asumsi lain**: kedalaman rongga kamera 15 mm, tinggi komponen di atas PCB 22 mm (ESP32 + heatsink).
4. **Rivet nut**: diameter lubang bergantung merek. Tanya toko atau ganti dengan baut + mur.
5. Uji dulu di kertas (PDF 1:1) lalu potongan kecil di MDF/akrilik sebelum memotong aluminium dan baja.

## Cetak 1:1 di kertas A4 (mock-up)

* Cetak **`out/cetak_A4_1to1.pdf` dengan "Ukuran sebenarnya / 100 %"**, bukan "Sesuaikan halaman". Tiap halaman punya
  penggaris 100 mm untuk dicek.
* Hal 1: `A1`. Hal 2–3: bagian kecil (beberapa per lembar). Hal 4 (landscape): `B1`. Tidak ada bagian yang dibelah.
* Tanda `+` merah = pusat lubang (tusuk dengan jarum). Garis hitam potong, garis putus biru lipat.
* Kertas tidak memodelkan tebal logam dan radius tekukan: untuk cek bentuk dan posisi lubang, bukan toleransi.

## Yang sudah diverifikasi

* 27 pemeriksaan otomatis lulus (lihat `out/parts_table.md`): PCB muat di bawah dinding atas, mur poros tidak menabrak PCB
  atau sirip, badan bisa berputar di bawah kaki lengan (sisa 5,1 mm), tumpukan baut cocok, kabel mendarat di grommet,
  semua lubang ≥ 3 mm dari zona tekuk, dll.
* Semua DXF dibaca ulang dan diaudit tanpa temuan; PDF cetak diukur: skala 100,2 mm per 100 mm (selisih = tebal garis),
  jarak isi ke tepi kertas ≥ 6,8 mm.
* **Belum**: simulasi lipatan di CAD dan percobaan fisik. Minta toko melakukan tinjauan DFM atas pola datar.

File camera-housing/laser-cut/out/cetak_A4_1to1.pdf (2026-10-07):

Pola potong 1:1 - A1 | hal 1/4

= 100 mm. Ukur dengan penggaris.

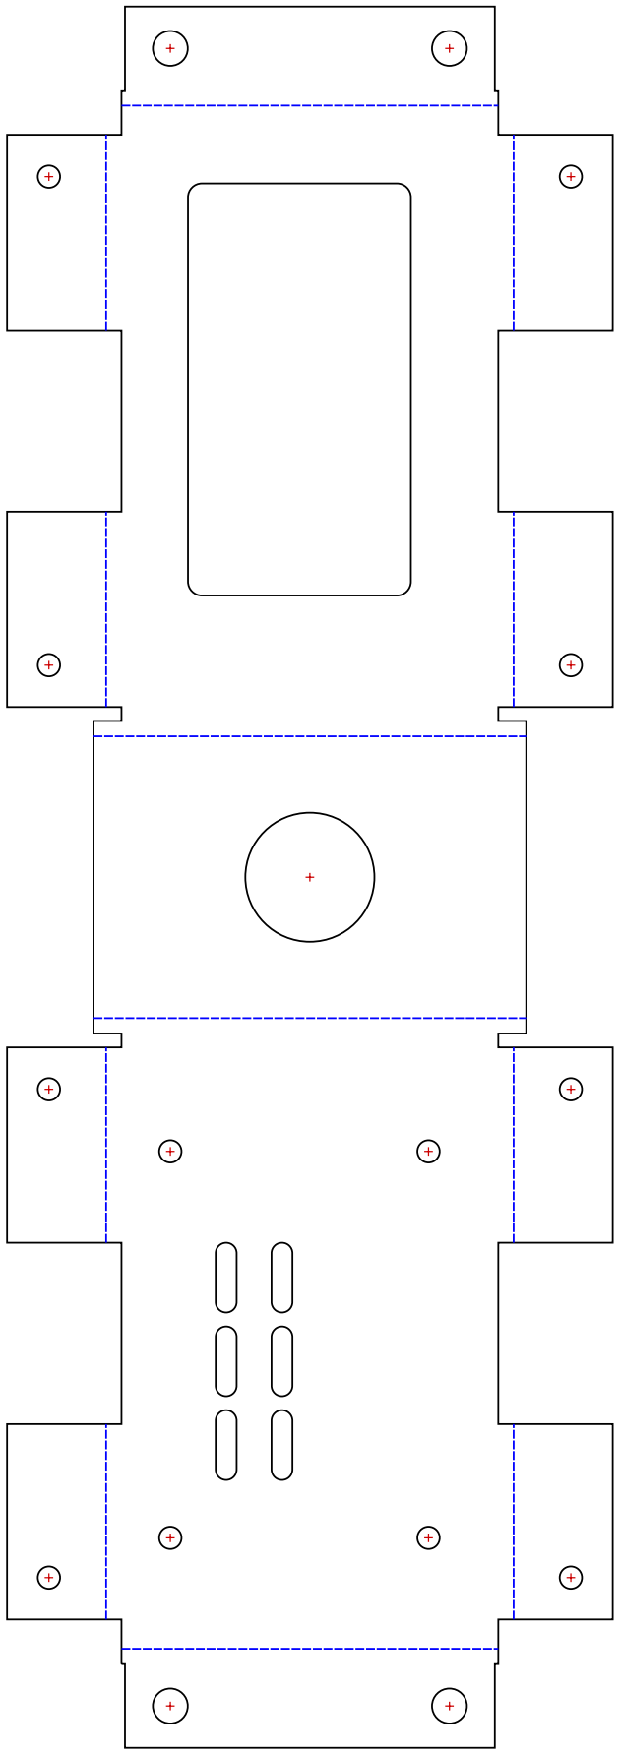
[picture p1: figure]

Cetak 'Ukuran sebenarnya' (100%), BUKAN 'Sesuaikan halaman'.

HITAM = potong | putus BIRU = lipat | + = pusat lubang (tusuk dengan jarum)

A1 Badan kamera - WADAH [Aluminium 2 mm] 87 x 250 mm

Pola potong 1:1 - B2, S1, S2, S3, A3, A2 | hal 2/4

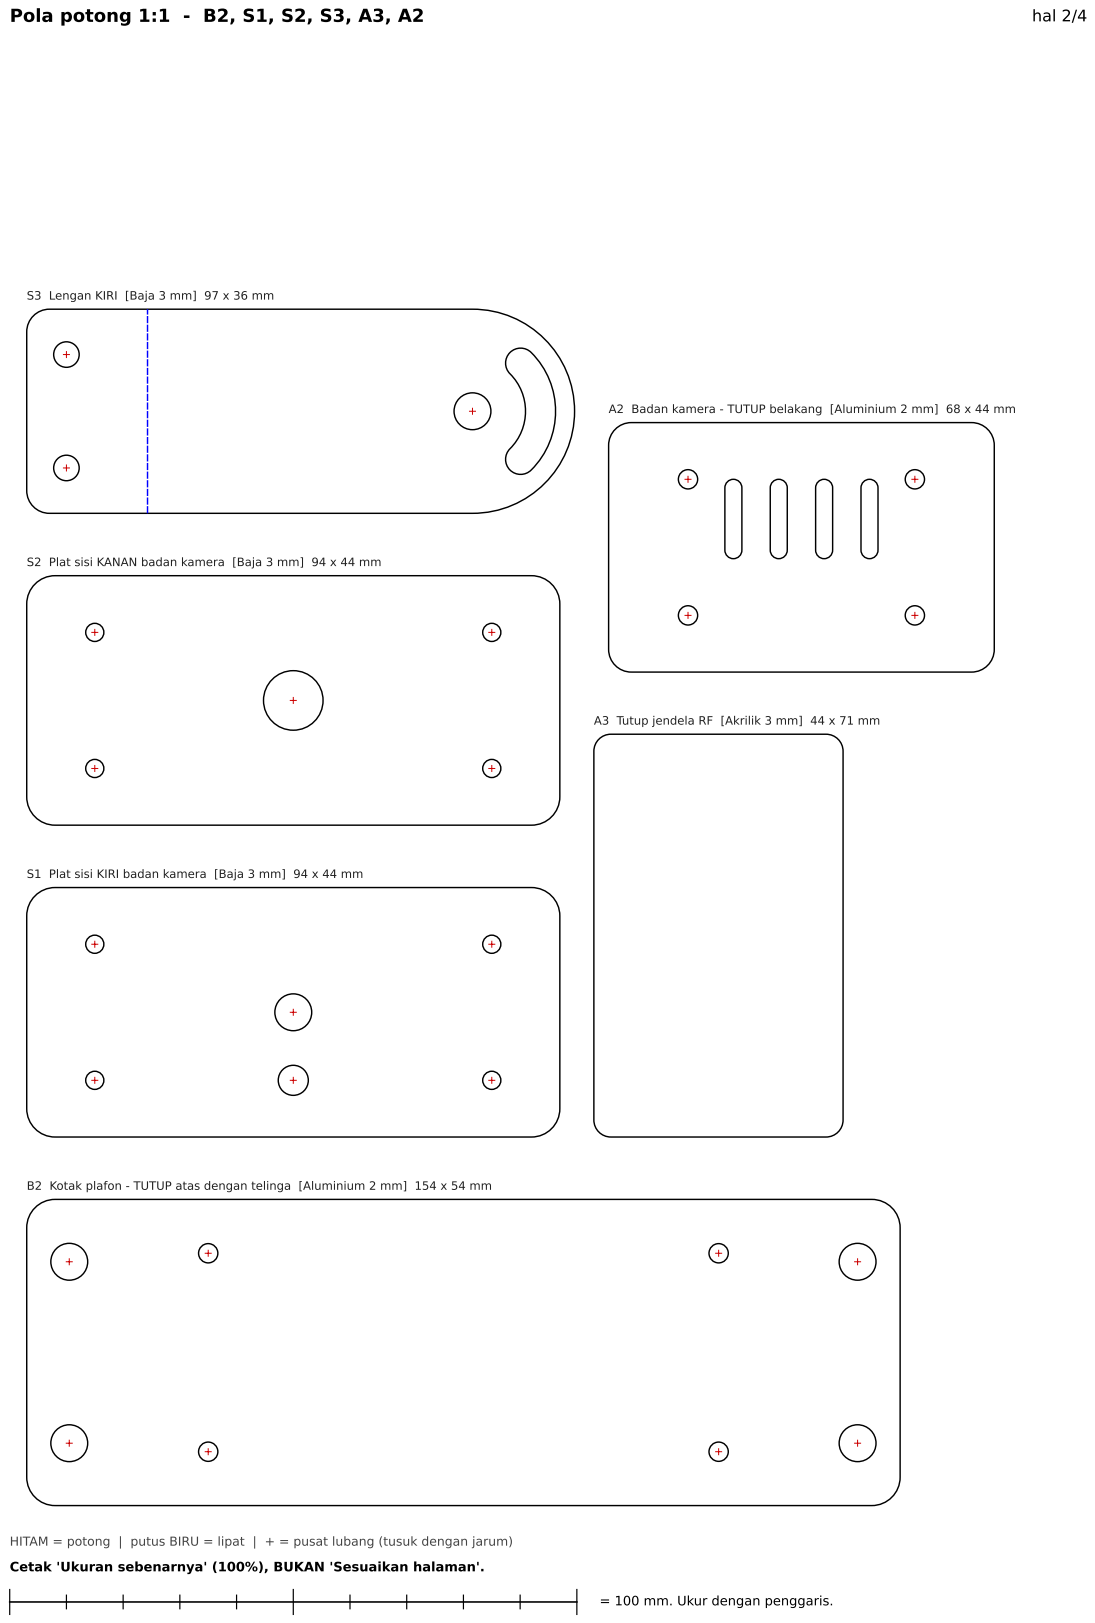
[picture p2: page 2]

S3 Lengan KIRI [Baja 3 mm] 97 x 36 mm

A2 Badan kamera - TUTUP belakang [Aluminium 2 mm] 68 x 44 mm

S2 Plat sisi KANAN badan kamera [Baja 3 mm] 94 x 44 mm

A3 Tutup jendela RF [Akrilik 3 mm] 44 x 71 mm

S1 Plat sisi KIRI badan kamera [Baja 3 mm] 94 x 44 mm

B2 Kotak plafon - TUTUP atas dengan telinga [Aluminium 2 mm] 154 x 54 mm

Pola potong 1:1 - S4 | hal 3/4

S4 Lengan KANAN [Baja 3 mm] 97 x 36 mm

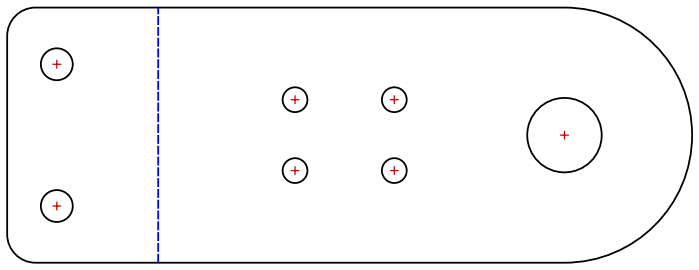
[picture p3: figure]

Pola potong 1:1 - B1 | hal 4/4

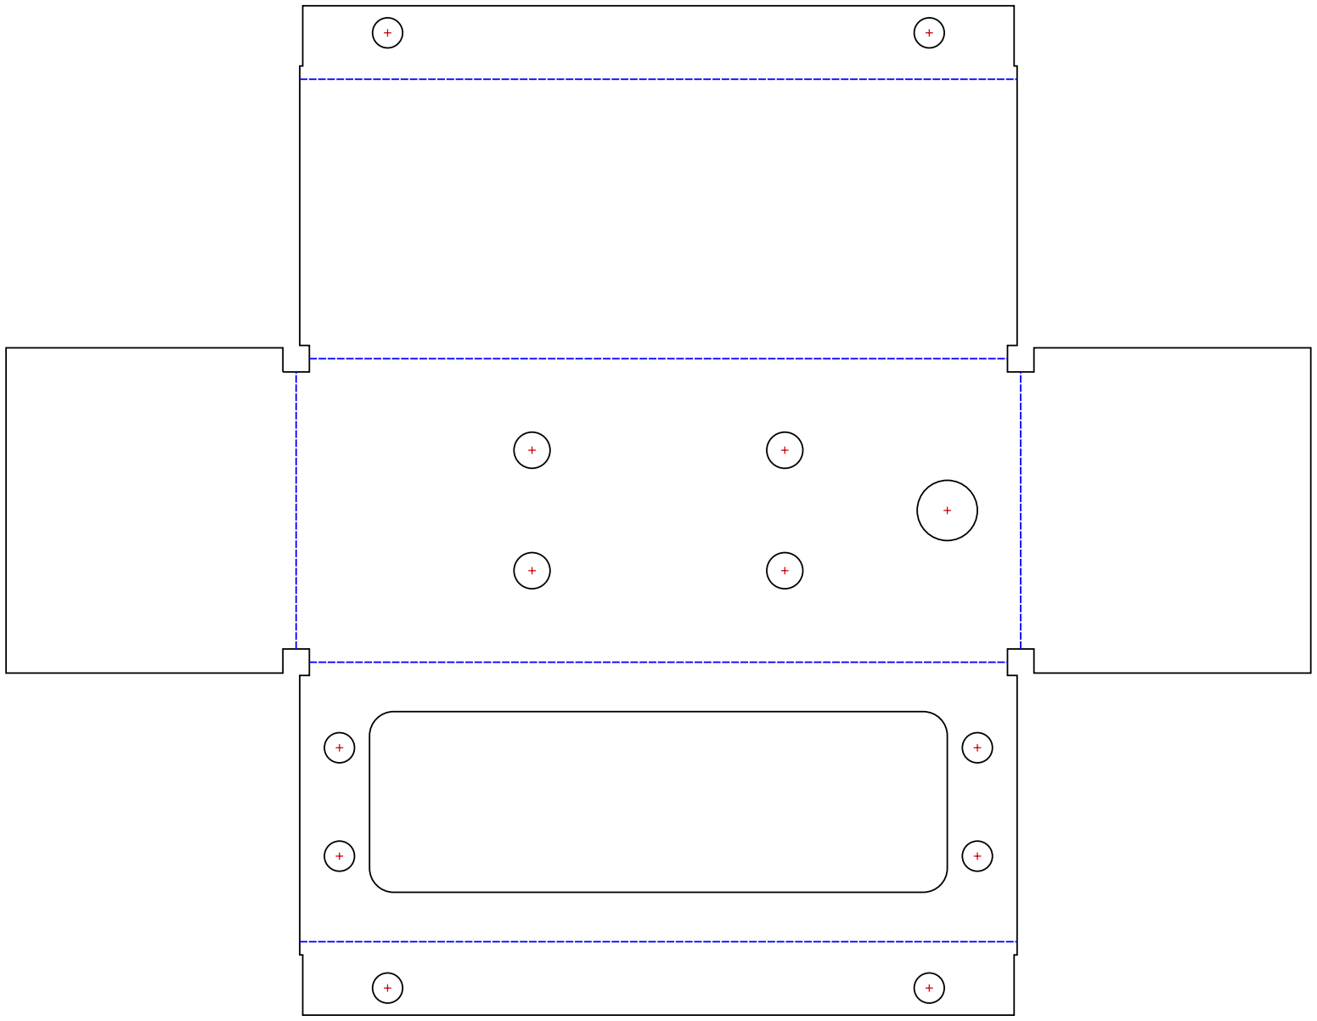
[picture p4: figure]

Cetak 'Ukuran sebenarnya' (100%), BUKAN 'Sesuaikan halaman'. HITAM = potong | putus BIRU = lipat | + = pusat lubang

B1 Kotak plafon - WADAH [Aluminium 2 mm] 217 x 168 mm

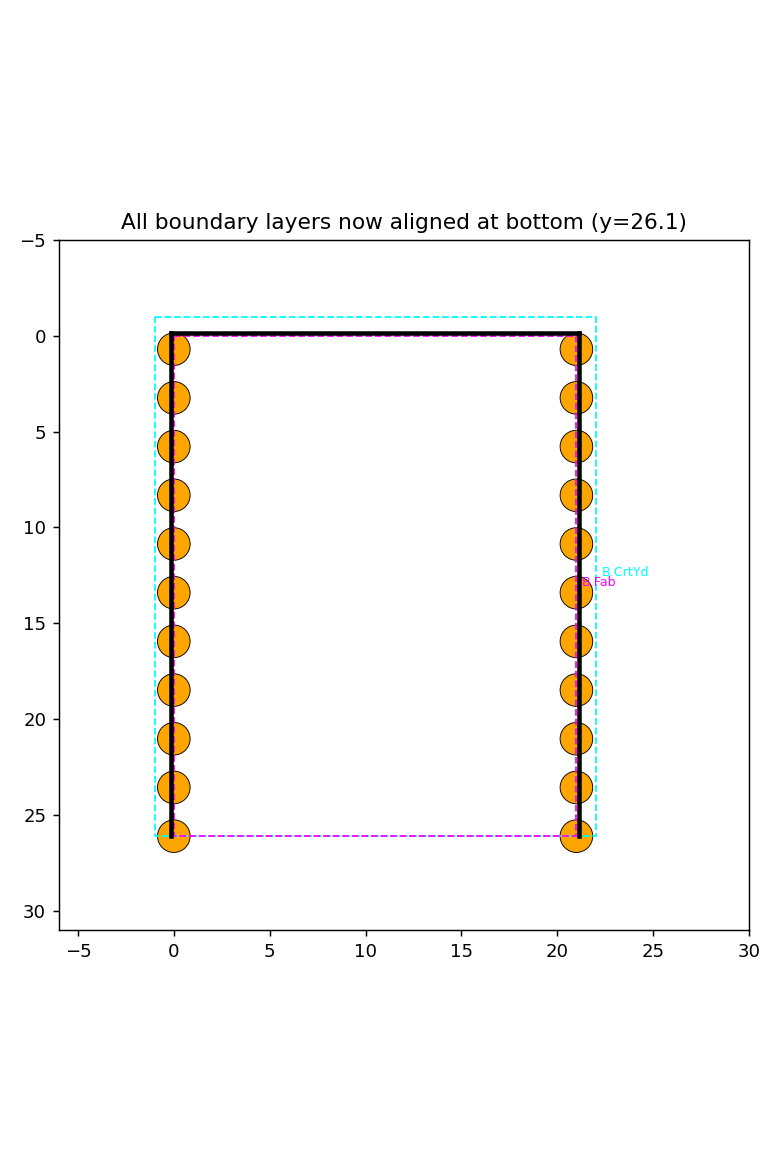
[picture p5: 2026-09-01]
LuckFox-RAP-Shield-PCB/_luckfox_alllayers_check.png

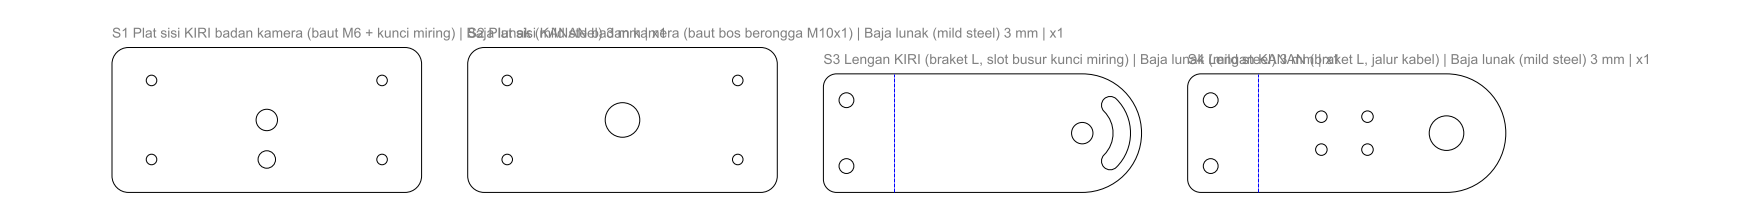
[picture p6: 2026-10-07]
camera-housing/laser-cut/out/png/sheet_baja_3mm.png

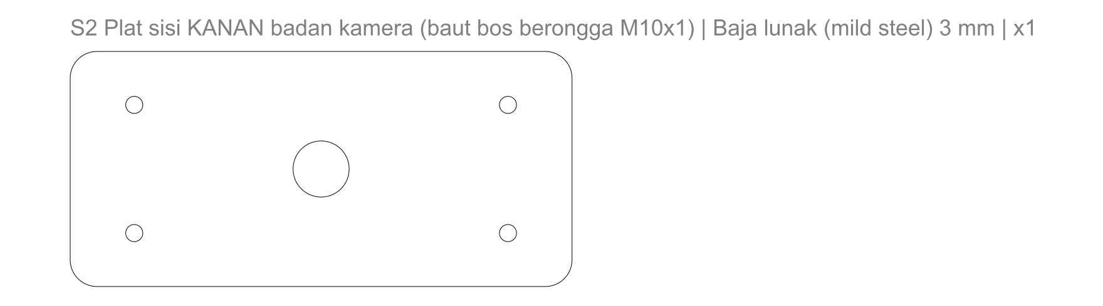
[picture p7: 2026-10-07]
camera-housing/laser-cut/out/png/S2.png

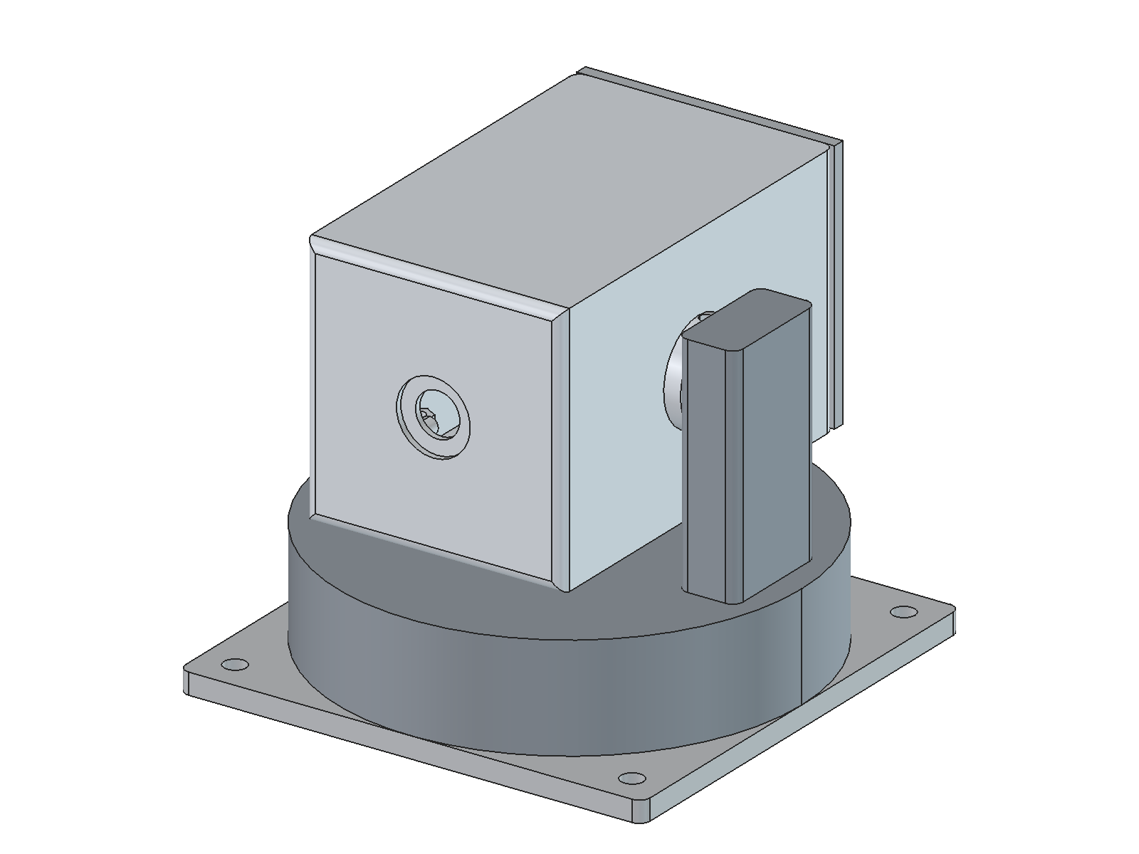
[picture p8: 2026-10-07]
camera-housing/hero_render.png

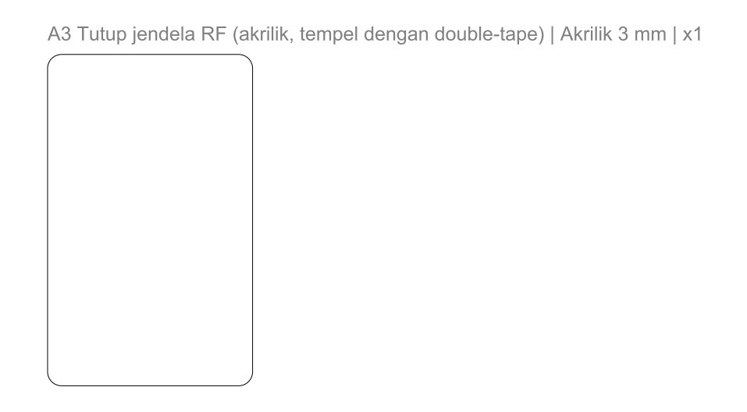
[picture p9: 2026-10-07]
camera-housing/laser-cut/out/png/A3.png

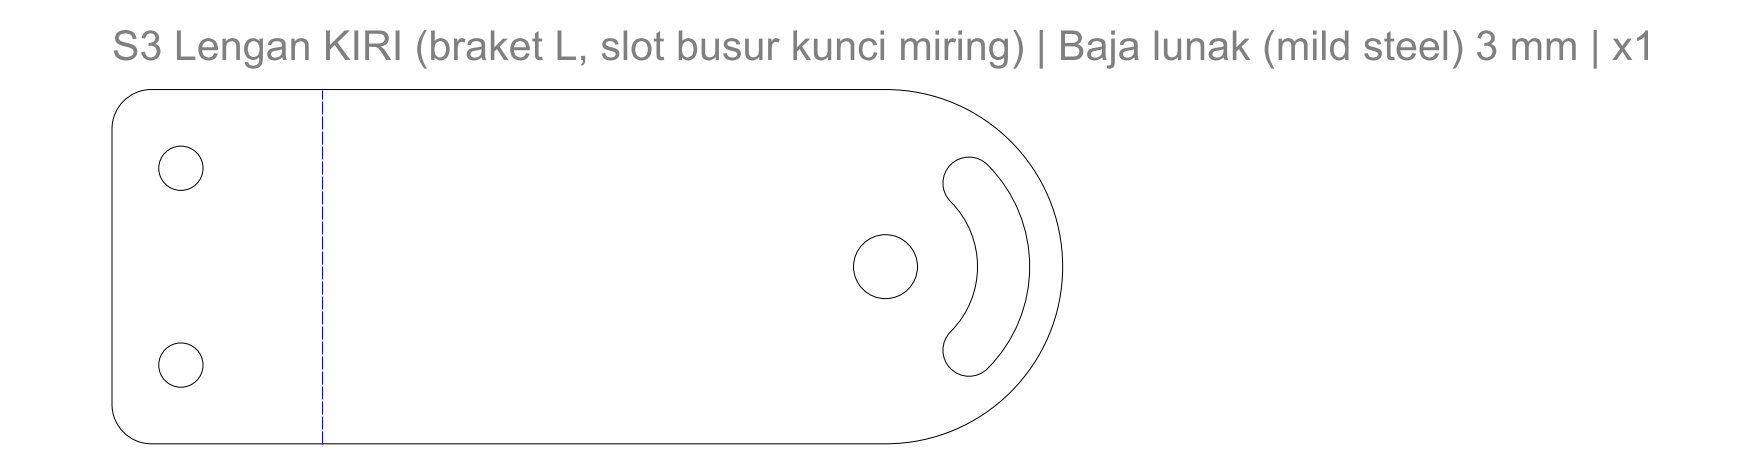
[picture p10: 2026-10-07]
camera-housing/laser-cut/out/png/S3.png

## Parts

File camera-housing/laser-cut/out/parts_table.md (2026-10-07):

| Kode | Komponen | Bahan | Tebal (mm) | Jml | Pola datar (mm) | Massa (g) | Tekuk |
|---|---|---|---|---|---|---|---|
| A1 | Badan kamera - WADAH (saluran: depan + atas + bawah) | Aluminium 5052-H32 | 2 | 1 | 87 x 250 | 80 | ya |
| A2 | Badan kamera - TUTUP belakang | Aluminium 5052-H32 | 2 | 1 | 68 x 44 | 15 | - |
| S1 | Plat sisi KIRI badan kamera (baut M6 + kunci miring) | Baja lunak (mild steel) | 3 | 1 | 94 x 44 | 95 | - |
| S2 | Plat sisi KANAN badan kamera (baut bos berongga M10x1) | Baja lunak (mild steel) | 3 | 1 | 94 x 44 | 94 | - |
| S3 | Lengan KIRI (braket L, slot busur kunci miring) | Baja lunak (mild steel) | 3 | 1 | 97 x 36 | 75 | ya |
| S4 | Lengan KANAN (braket L, jalur kabel) | Baja lunak (mild steel) | 3 | 1 | 97 x 36 | 75 | ya |
| B1 | Kotak plafon - WADAH (tray terbuka di atas) | Aluminium 5052-H32 | 2 | 1 | 217 x 168 | 118 | ya |
| B2 | Kotak plafon - TUTUP atas dengan telinga | Aluminium 5052-H32 | 2 | 1 | 154 x 54 | 44 | - |
| A3 | Tutup jendela RF (akrilik, tempel dengan double-tape) | Akrilik | 3 | 1 | 44 x 71 | 11 | - |

Massa total: Aluminium 5052-H32 256 g, Baja lunak (mild steel) 339 g, Akrilik 11 g

Lembar nesting (file di `out/sheets/`):

- `sheet_aluminium_2mm.dxf`: Aluminium 5052-H32 2 mm, 4 bagian, area 568 x 250 mm
- `sheet_baja_3mm.dxf`: Baja lunak (mild steel) 3 mm, 4 bagian, area 423 x 44 mm
- `sheet_akrilik_3mm.dxf`: Akrilik 3 mm, 1 bagian, area 44 x 71 mm

Pemeriksaan otomatis yang lulus:

- OK: vent slot clear of standoff screws (19.8 mm)
- OK: vent slot clear of standoff screws (26.5 mm)
- OK: vent slot clear of standoff screws (15.5 mm)
- OK: vent slot clear of standoff screws (24.2 mm)
- OK: vent slot clear of standoff screws (29.9 mm)
- OK: vent slot clear of standoff screws (20.8 mm)
- OK: PCB stack fits under the top wall (38.6 <= 40.0)
- OK: PCB clears the rear flange (USB-C overhang ~5 mm) (85.2 <= 92.0)
- OK: room for the pivot nuts either side of the PCB (left 7.0, right 10.0 mm)
- OK: RF window inside the top wall's flat width
- OK: lens window fits the front plate (18.5 <= 36.0)
- OK: tilt-lock slot stays inside the arm width (11.1 <= 16.0)
- OK: body can rotate under the box feet (>= 3 mm) (5.1 mm)
- OK: arm strip is wide enough around the boss hole
- OK: hollow stud (25 mm) sticks out >= 0.5 mm past the jam nut (stud end x=50.0, nuts end x=47.5)
- OK: right pivot nut + washer clear the PCB (intrusion 6.0 mm, PCB margin 10.0 mm)
- OK: left M6 head + washer clear the PCB (intrusion 5.6 mm, margin 7.0 mm)
- OK: tab gap leaves room for the pivot nut (tabs end at d=34, restart at d=60, pivot at d=47)
- OK: cable S-curve to the grommet is gentle (radius >= 25 mm) (rises at x=62.0, grommet x=48.0, S radius ~41 mm)
- OK: grommet clear of the arm foot (>= 3 mm) (5.0 mm)
- OK: grommet inside the flat part of the box base (53.0 + 3 <= 58.0)
- OK: plate interface fits the wall's flat height (40.0 <= 42.0)
- OK: plate interface fits the wall's flat width
- OK: plate screws keep a web >= 2 mm beside the opening (2.5 mm)
- OK: plate screws keep >= 2 mm to the plate edge
- OK: arm foot fits under the box
- OK: arm legs sit inside the box footprint in Y (18.0 <= 23.0)

Fakta per bagian:

- A1: Pelat dasar 62 x 44 mm (ukuran LUAR), kedalaman dinding 94 mm
- A1: Tekukan 90 derajat x 12, r dalam 2, K=0.4, BA=4.398, setback=4
- A1: Pola datar 86.8 x 249.6 mm
- A1: Jendela RF 32 x 59 mm di dinding atas (tutup akrilik A3)
- S3: Panjang pola datar 96.6 mm (s_axis=78.6), lebar 36 mm
- S3: Kaki 24 mm luar, lurus ke tengah; sumbu 60 mm di bawah dasar kotak
- S4: Panjang pola datar 96.6 mm (s_axis=78.6), lebar 36 mm
- S4: Kaki 24 mm luar, lurus ke tengah; sumbu 60 mm di bawah dasar kotak
- B1: Pelat dasar 124 x 54 mm (ukuran LUAR), kedalaman dinding 50 mm
- B1: Tekukan 90 derajat x 6, r dalam 2, K=0.4, BA=4.398, setback=4
- B1: Pola datar 216.8 x 167.6 mm
- B1: Bukaan sisi 96 x 30 mm di dinding +Y; 4 lubang rivet nut M3 untuk plat 116 x 40 mm (plat belum dibuat)

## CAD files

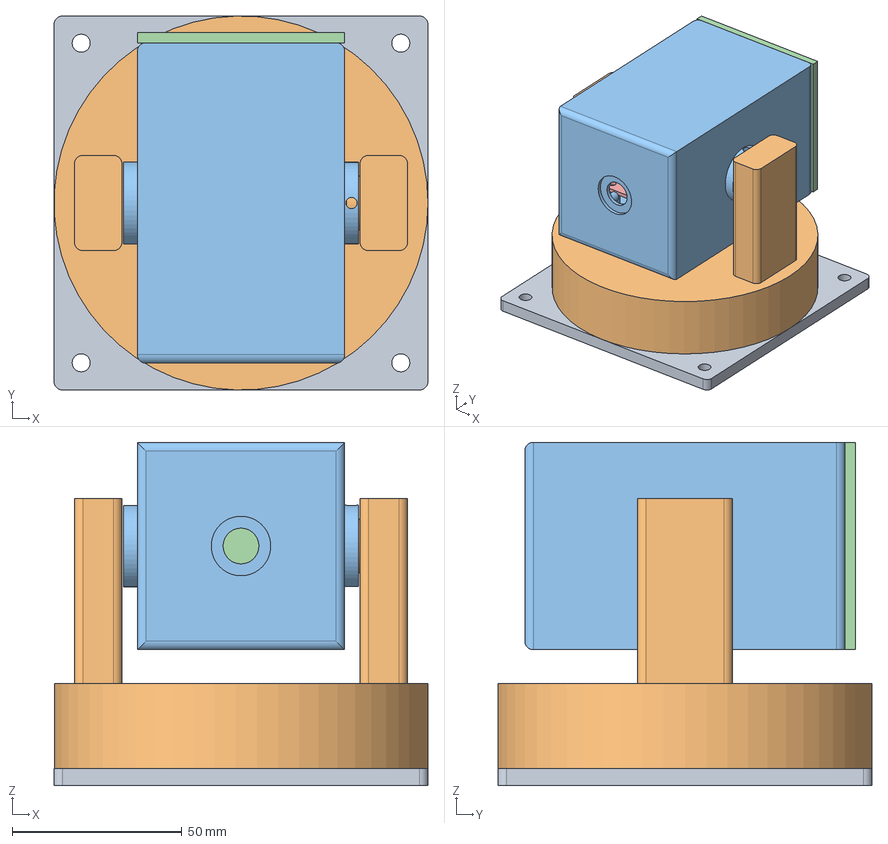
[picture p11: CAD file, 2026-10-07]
camera-housing/full_assembly.FCStd
110.0 x 110.0 x 101.0 mm
CeilingMount
ComponentBox
CameraBody
BackCover
PCB

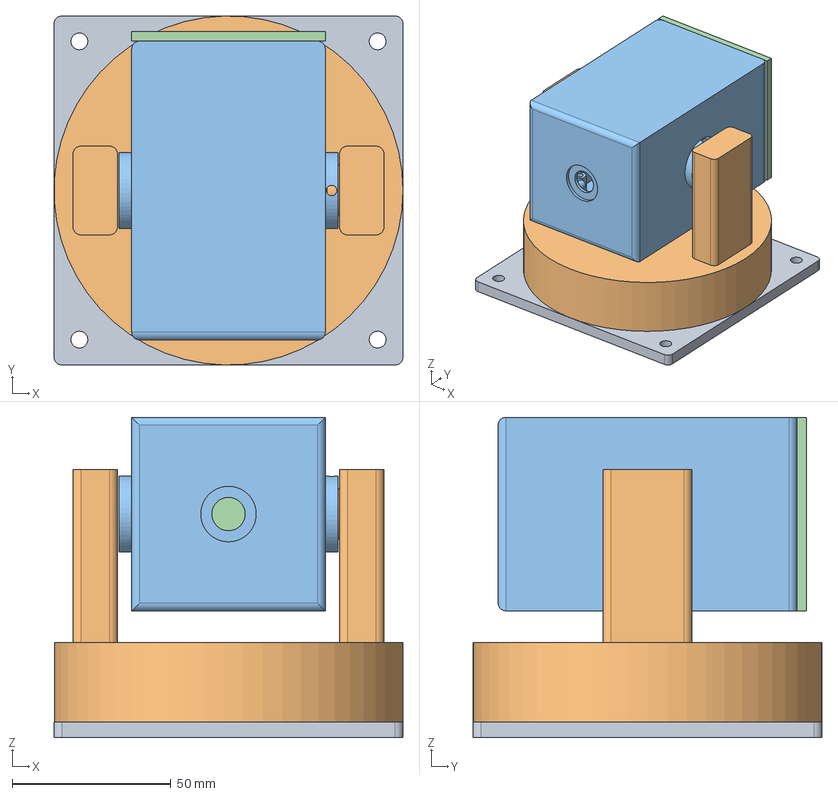
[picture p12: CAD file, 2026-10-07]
camera-housing/camera_casing.FCStd
110.0 x 110.0 x 101.0 mm
CeilingMount
ComponentBox
CameraBody
BackCover

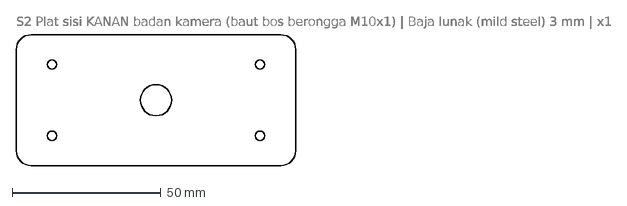
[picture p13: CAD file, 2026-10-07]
camera-housing/laser-cut/out/dxf/S2_plat_sisi_kanan_bos_kabel.dxf
S2 Plat sisi KANAN badan kamera (baut bos berongga M10x1) | Baja lunak (mild steel) 3 mm | x1

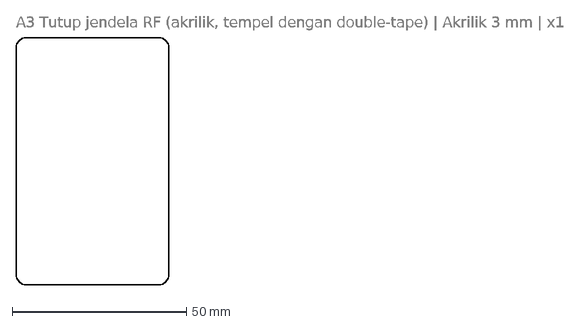
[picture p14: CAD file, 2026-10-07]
camera-housing/laser-cut/out/sheets/sheet_akrilik_3mm.dxf
A3 Tutup jendela RF (akrilik, tempel dengan double-tape) | Akrilik 3 mm | x1

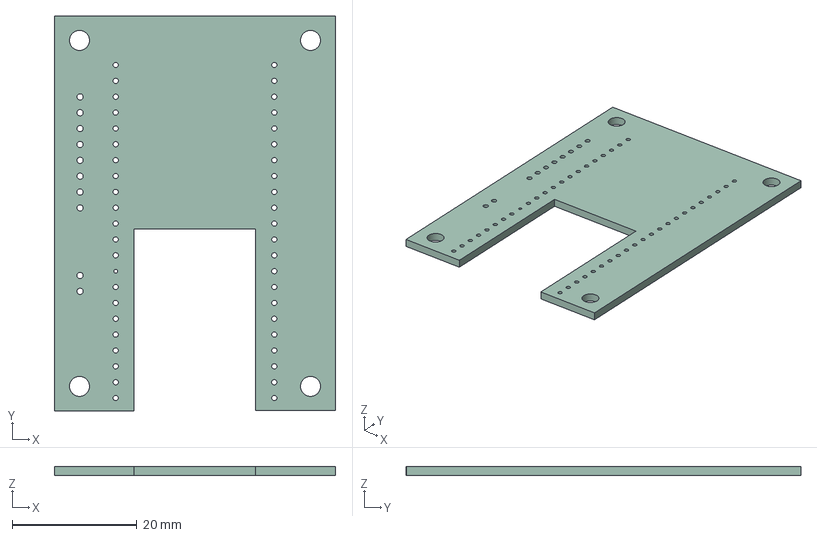
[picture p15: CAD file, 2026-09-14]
LuckFox-RAP-Shield-PCB/3d/LuckFox RAP Shield.step
45.0 x 63.2 x 1.51 mm

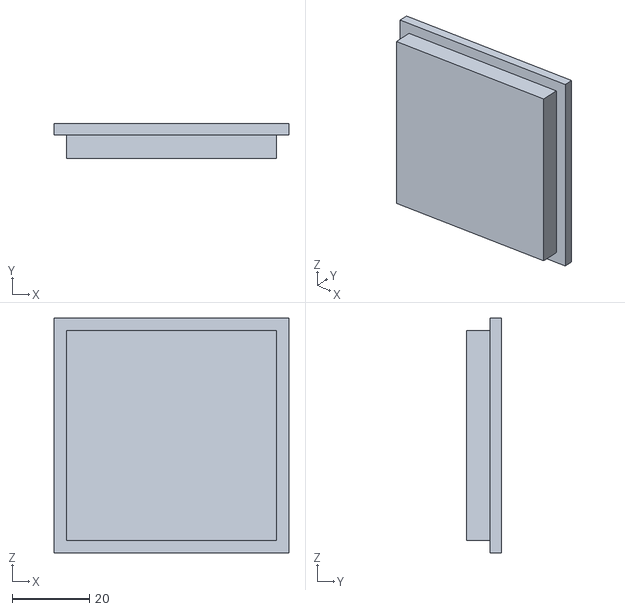
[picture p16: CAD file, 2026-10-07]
camera-housing/BackCover.stl
61.0 x 9.00 x 61.0

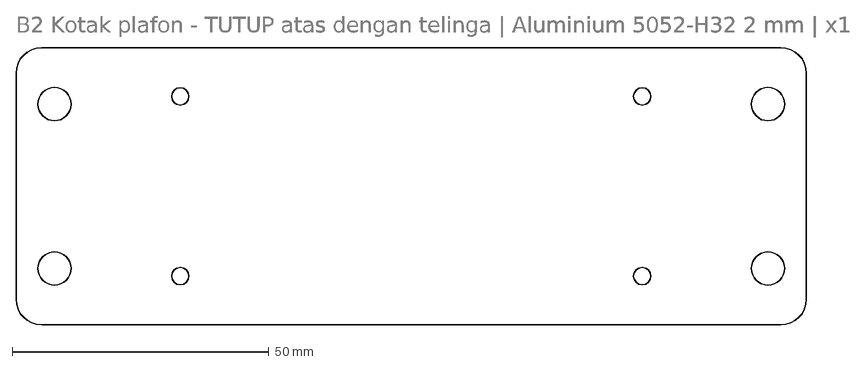
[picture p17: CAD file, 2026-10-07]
camera-housing/laser-cut/out/dxf/B2_kotak_plafon_tutup_telinga.dxf
B2 Kotak plafon - TUTUP atas dengan telinga | Aluminium 5052-H32 2 mm | x1

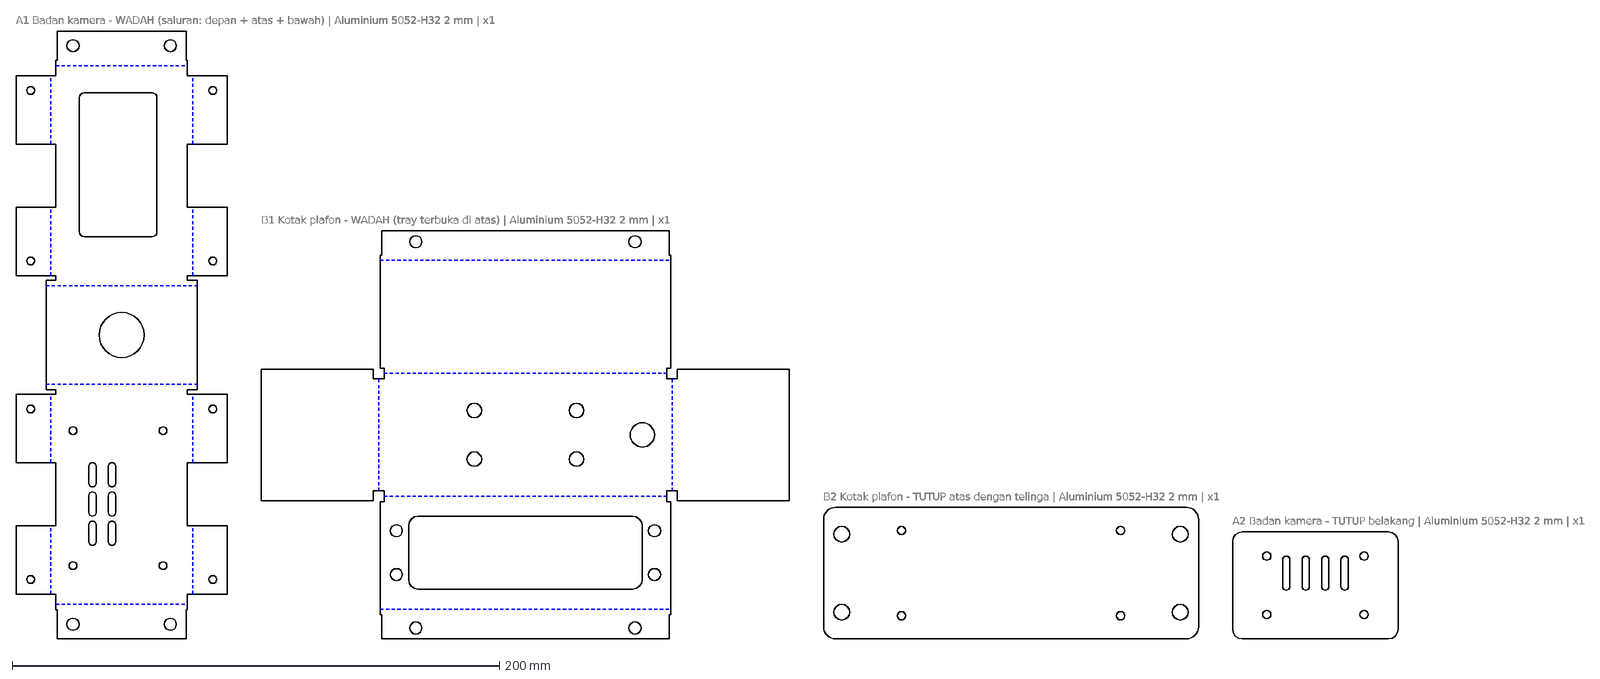
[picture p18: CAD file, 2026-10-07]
camera-housing/laser-cut/out/sheets/sheet_aluminium_2mm.dxf
A1 Badan kamera - WADAH (saluran: depan + atas + bawah) | Aluminium 5052-H32 2 mm | x1
B1 Kotak plafon - WADAH (tray terbuka di atas) | Aluminium 5052-H32 2 mm | x1
B2 Kotak plafon - TUTUP atas dengan telinga | Aluminium 5052-H32 2 mm | x1
A2 Badan kamera - TUTUP belakang | Aluminium 5052-H32 2 mm | x1

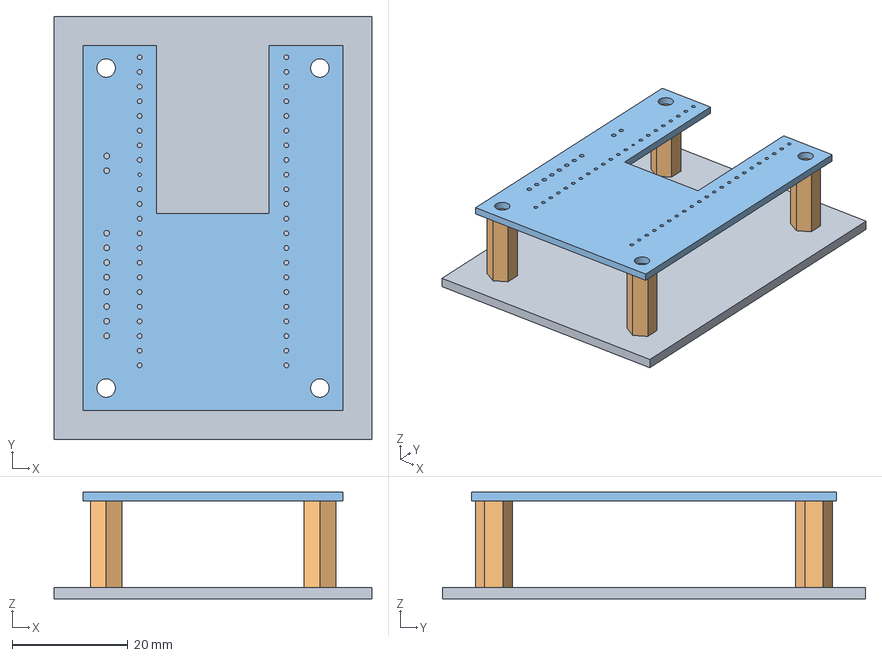
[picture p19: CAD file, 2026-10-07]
camera-housing/camera_housing.FCStd
55.0 x 73.2 x 18.5 mm
Base
Standoffs
PCB

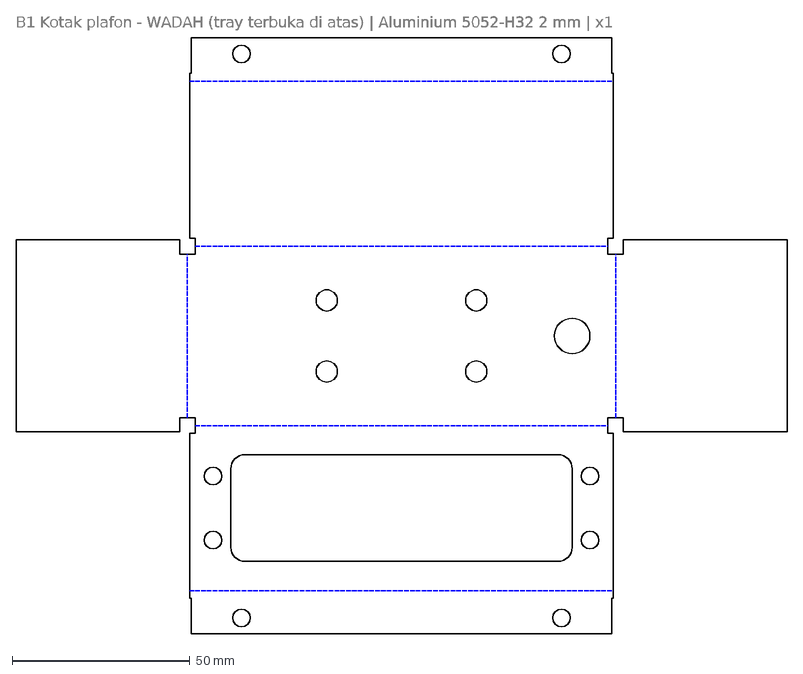
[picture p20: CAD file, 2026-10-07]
camera-housing/laser-cut/out/dxf/B1_kotak_plafon_wadah.dxf
B1 Kotak plafon - WADAH (tray terbuka di atas) | Aluminium 5052-H32 2 mm | x1

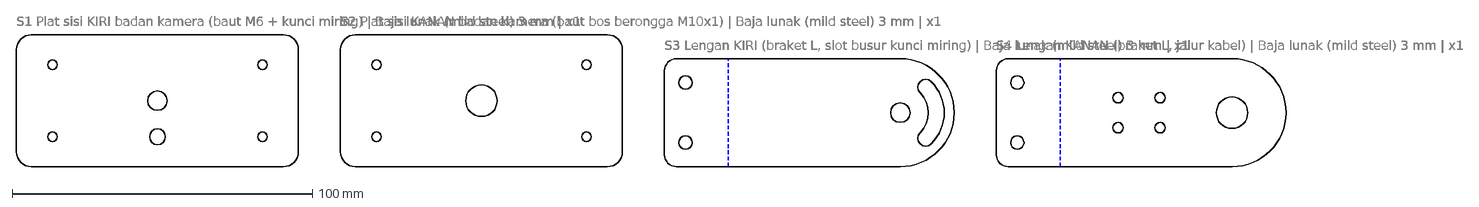
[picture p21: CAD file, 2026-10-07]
camera-housing/laser-cut/out/sheets/sheet_baja_3mm.dxf
S1 Plat sisi KIRI badan kamera (baut M6 + kunci miring) | Baja lunak (mild steel) 3 mm | x1
S2 Plat sisi KANAN badan kamera (baut bos berongga M10x1) | Baja lunak (mild steel) 3 mm | x1
S3 Lengan KIRI (braket L, slot busur kunci miring) | Baja lunak (mild steel) 3 mm | x1
S4 Lengan KANAN (braket L, jalur kabel) | Baja lunak (mild steel) 3 mm | x1

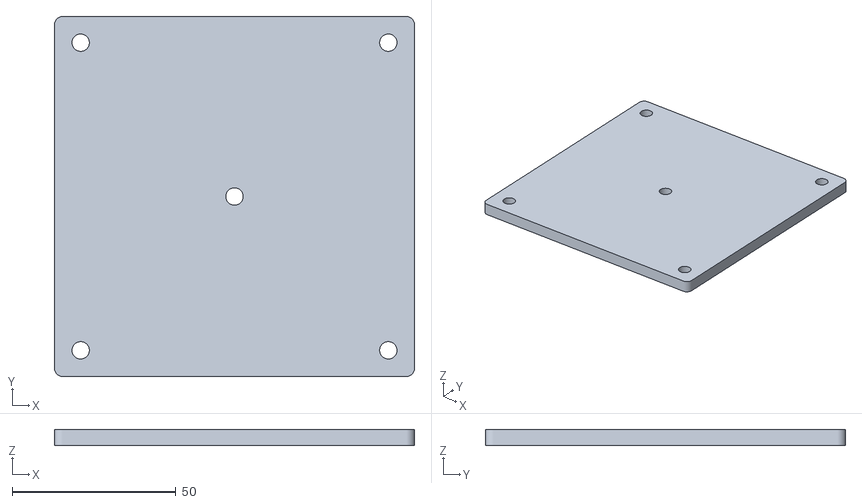
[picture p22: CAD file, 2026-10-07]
camera-housing/CeilingMount.stl
110.0 x 110.0 x 5.00

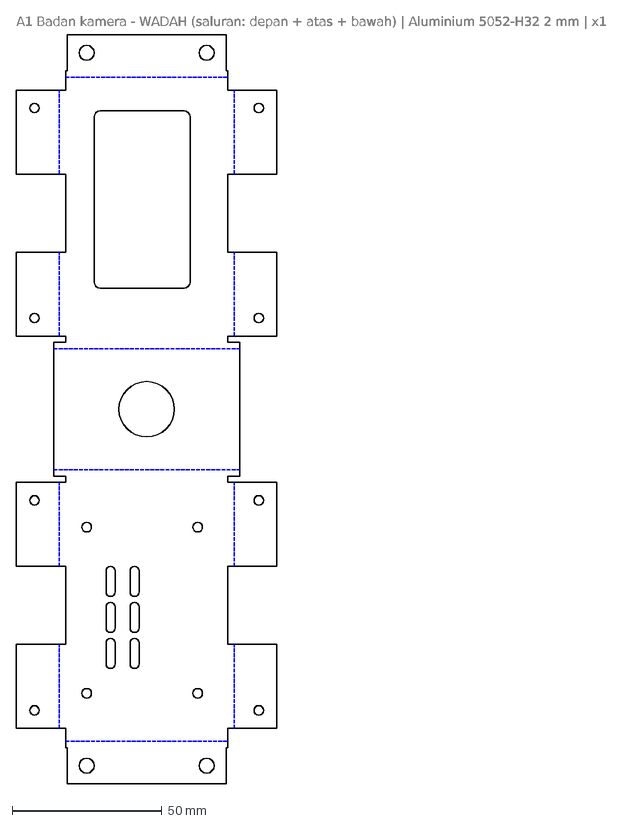
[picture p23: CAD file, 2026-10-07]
camera-housing/laser-cut/out/dxf/A1_wadah_badan_kamera.dxf
A1 Badan kamera - WADAH (saluran: depan + atas + bawah) | Aluminium 5052-H32 2 mm | x1

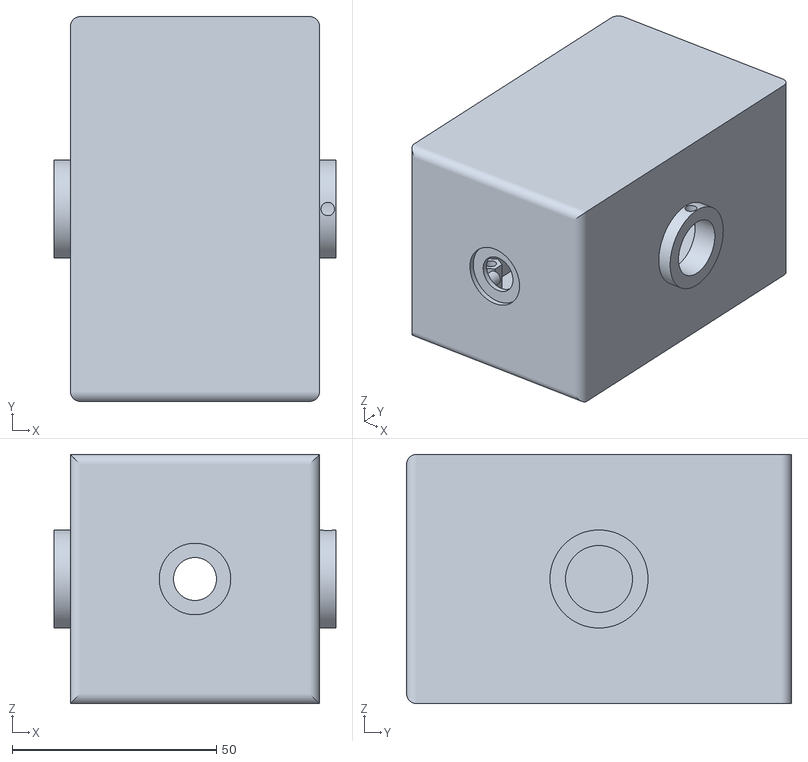
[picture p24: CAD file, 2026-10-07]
camera-housing/CameraBody.stl
69.0 x 94.2 x 61.0

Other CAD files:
camera-housing/laser-cut/out/dxf/S1_plat_sisi_kiri.dxf
camera-housing/laser-cut/out/dxf/A2_tutup_badan_kamera.dxf
camera-housing/ComponentBox.stl
camera-housing/laser-cut/out/dxf/S3_lengan_kiri_slot.dxf
camera-housing/laser-cut/out/dxf/A3_tutup_jendela_RF_akrilik.dxf
camera-housing/laser-cut/out/dxf/S4_lengan_kanan_kabel.dxf

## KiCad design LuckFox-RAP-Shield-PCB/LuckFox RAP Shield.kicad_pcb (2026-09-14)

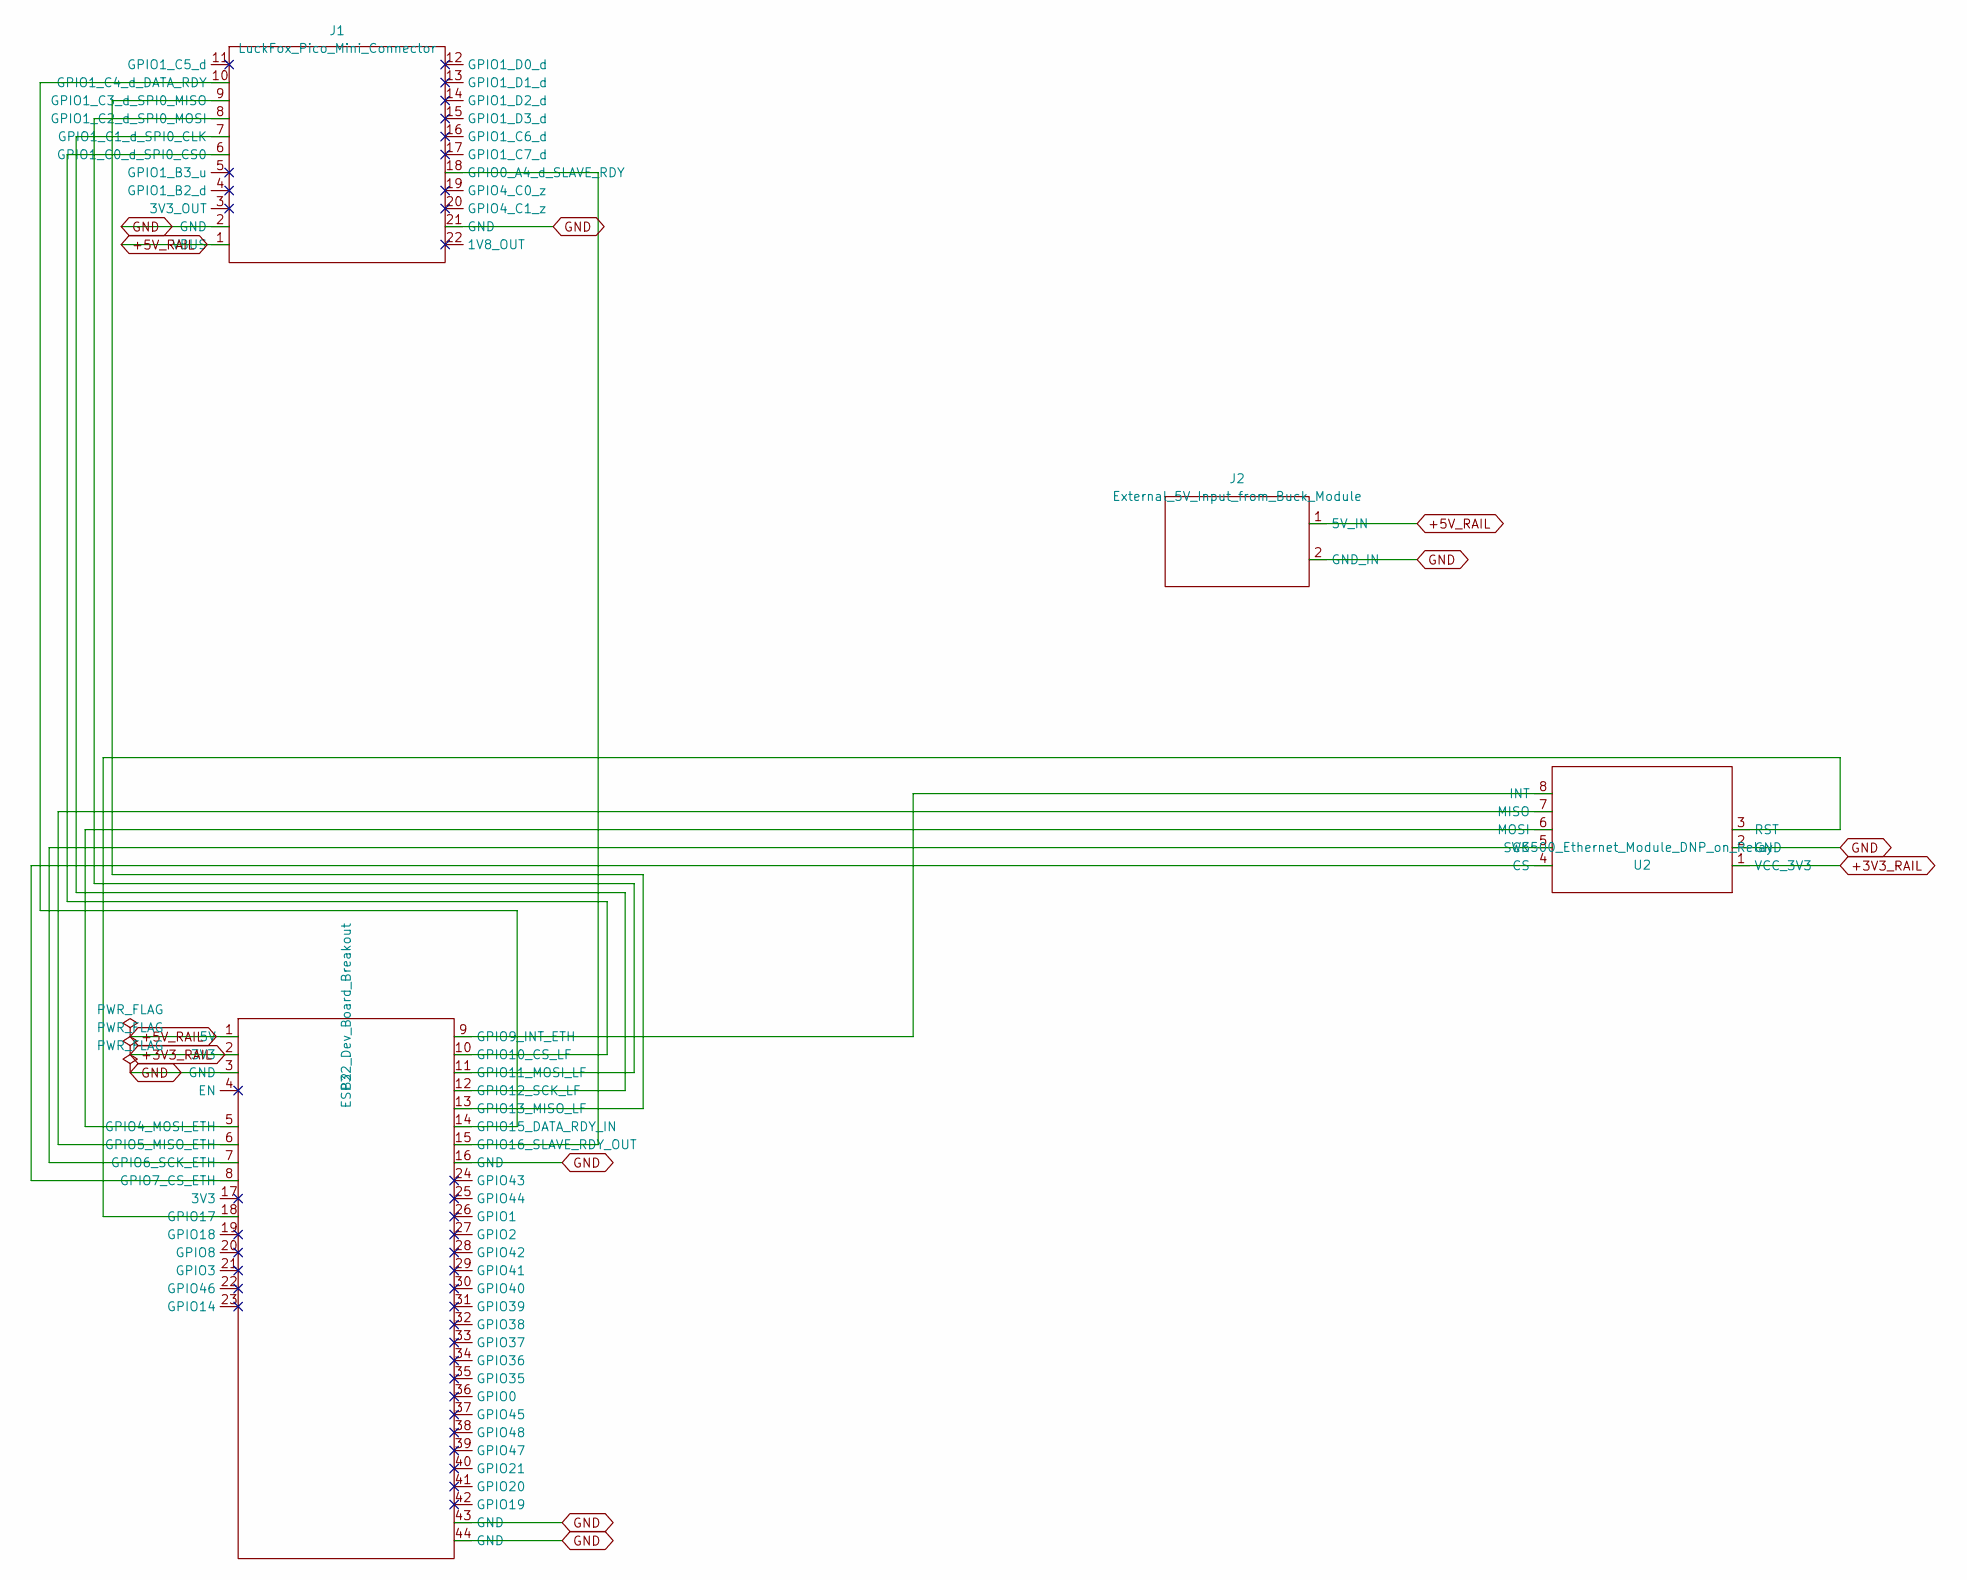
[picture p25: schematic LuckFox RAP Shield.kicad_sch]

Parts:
B2: ESP32_Dev_Board_Breakout
J1: LuckFox_Pico_Mini_Connector; LuckFox_Pico_Mini
J2: External_5V_Input_from_Buck_Module; PinHeader_1x02_P2.54mm_Vertical
U2: W5500_Ethernet_Module_DNP_on_Relay; PinHeader_1x08_P2.54mm_Vertical

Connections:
+3V3_RAIL: B2.2 (3V3), U2.1 (VCC_3V3)
+5V_RAIL: B2.1 (5V), J1.1 (VBUS), J2.1 (5V_IN)
GND: B2.3 (GND), B2.16 (GND), B2.43 (GND), B2.44 (GND), J1.2 (GND), J1.21 (GND), J2.2 (GND_IN), U2.2 (GND)
unnamed: B2.5 (GPIO4_MOSI_ETH), U2.6 (MOSI)
unnamed: B2.6 (GPIO5_MISO_ETH), U2.7 (MISO)
unnamed: B2.7 (GPIO6_SCK_ETH), U2.5 (SCK)
unnamed: B2.8 (GPIO7_CS_ETH), U2.4 (CS)
unnamed: B2.9 (GPIO9_INT_ETH), U2.8 (INT)
unnamed: B2.10 (GPIO10_CS_LF), J1.6 (GPIO1_C0_d_SPI0_CS0)
unnamed: B2.11 (GPIO11_MOSI_LF), J1.8 (GPIO1_C2_d_SPI0_MOSI)
unnamed: B2.12 (GPIO12_SCK_LF), J1.7 (GPIO1_C1_d_SPI0_CLK)
unnamed: B2.13 (GPIO13_MISO_LF), J1.9 (GPIO1_C3_d_SPI0_MISO)
unnamed: B2.14 (GPIO15_DATA_RDY_IN), J1.10 (GPIO1_C4_d_DATA_RDY)
unnamed: B2.15 (GPIO16_SLAVE_RDY_OUT), J1.18 (GPIO0_A4_d_SLAVE_RDY)
unnamed: B2.18 (GPIO17), U2.3 (RST)

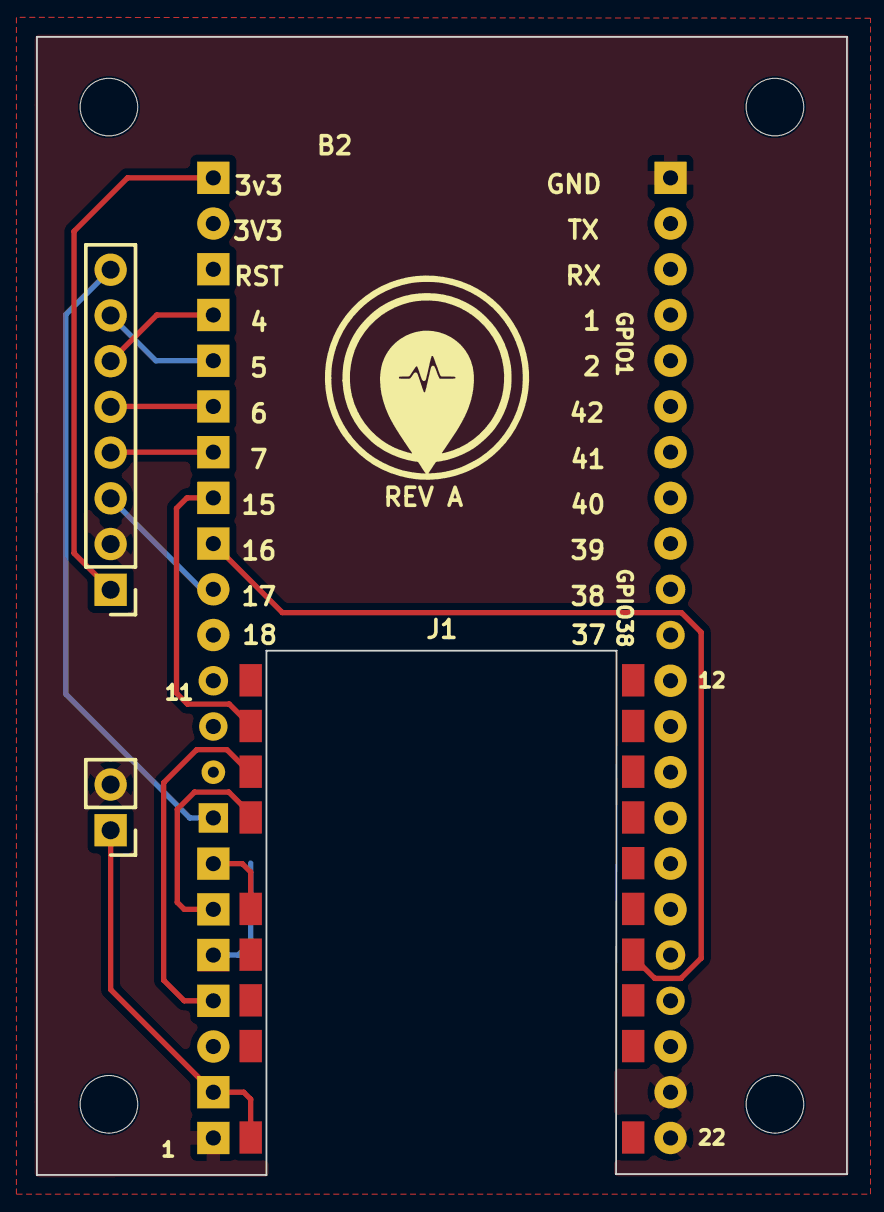
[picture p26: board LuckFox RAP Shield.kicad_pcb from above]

Board: 2 copper layers, 45.0 x 63.2 mm, 8 parts (1 on the bottom side), 15 nets.

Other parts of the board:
H1, H2, H3, H4: MountingHole_3.2mm_M3

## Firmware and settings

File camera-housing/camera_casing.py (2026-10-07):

"""
Futuristic-minimalist camera BODY + manual 2-axis (pan/tilt) hinge.

The LuckFox RAP Shield PCB lives INSIDE this body along with the SC3336 module up front
behind the lens -- no external FPC run, the ribbon stays entirely inside one enclosure.
`build_housing.py`'s Base/Standoffs still exist and still work standalone if a flat
non-pivoting mount is ever wanted, but this file only imports board/PCB dimension
constants from it, not its build functions.

Heatsink work on the LuckFox Pico Mini still doesn't require touching the pan/tilt
mechanics: CameraBody has a removable BackCover (a few M3 self-tap screws) giving full
access to the PCB compartment without disturbing CeilingMount/ComponentBox/the hinge pins.

TILT HINGE IS ON THE LEFT/RIGHT SIDES of CameraBody (not a single bottom tab like the
first revision) -- two independent side pivots instead of one center yoke, on request.

STYLED AFTER DJI OSMO POCKET'S GIMBAL, on request: both pivots show the SAME flat disc
diameter (HINGE_DISC_OD) on CameraBody, whether solid (left) or bushing (right) -- not a
small boss on one side and a noticeably bigger one on the other. An earlier revision grew
the right boss alone (to ~22.4mm) just to contain its bushing hole while the left stayed
16mm; that was functionally fine but LOOKED like an odd separate "big tube" bolted on --
unifying both sides to one disc size fixes that. The reach was also shortened again in
this same pass (see "tightened" notes below) -- Osmo Pocket's pivot housings sit close and
flush, not on a long stalk.

THE SPIGOT LIVES ON THE ARM, NOT ON CAMERABODY. This is the key point: the arm (fixed to
ComponentBox) is STATIONARY with respect to TILT -- only CameraBody tilts (ComponentBox
itself does pan, but that's a separate axis, and the arm/spigot geometry is fixed relative
to ComponentBox regardless of pan angle). An earlier revision put the hollow shaft on
CameraBody instead (the part that ROTATES for tilt), which meant a hole connecting its bore
to anything else would only stay aligned across a limited tilt angle, since the hole would
sweep around as CameraBody rotated. Putting the spigot on the arm (stationary relative to
tilt) instead means a hole in its underside stays permanently connected to ComponentBox's
down-channel (see below) at ANY tilt angle -- no rotation-related misalignment, because
nothing at that joint is moving (tilt-wise).

Because of this, the two tilt pivots are mechanically different, and which side holds
which part matters:
  LEFT  pivot: solid, M5 wing bolt + wing nut through CameraBody's left disc and
               ComponentBox's left arm -- this is the structural/load-bearing side and the
               friction lock for the tilt angle.
  RIGHT pivot: ComponentBox's arm has a SHORT spigot (SPIGOT_OD outer, CABLE_HOLE_D bore,
               stationary relative to tilt, printed as one piece with the arm) -- just long enough
               (SPIGOT_LEN) to cross PIVOT_GAP and engage partway into CameraBody's disc,
               for real rotational support without reaching all the way to the wall. The
               CABLE's own path is a separate, longer bore cut independently (see below) --
               decoupled from how much solid spigot material there is. CameraBody's right
               disc just has a plain round bushing hole (same HINGE_DISC_OD outside, no
               spigot of its own) that the arm's spigot inserts into and rotates around. A
               radial M4 set-screw through CameraBody's disc (the ROTATING part now)
               presses inward on the stationary spigot for friction-lock.
  Retention caveat (search "NOT positively retained" below): the spigot isn't positively
  locked against CameraBody sliding back off it, only friction-held by the set-screw and
  by the left bolt keeping the body's attitude fixed. Fine for a first build; add a dab of
  glue or a zip-tie there if more security is wanted.

THE PAN PIVOT IS ALSO SOLID (plain M5 bolt, like the left tilt pivot) -- it does not carry
the cable either. Cable path, entirely enclosed the whole way (on request -- never open to
outside air, and never exiting any side face):
  right tilt spigot's bore -> continues through the arm's own body (one continuous bore,
  independent of the spigot's own shorter length) -> turns down through a hidden vertical
  channel inside the arm -> crosses ComponentBox's own top wall (ONE wall-hop now, not two
  -- see "COMPONENTBOX IS NOW A ROUND ROTATING TURRET" above for why) -> arrives inside
  ComponentBox's own interior, where the W5500 + buck converter will eventually live
  (mounting for them still not designed, out of scope for now).
CeilingMount has NO cable hole -- the electronics moved onto the rotating ComponentBox
itself, so there's nothing left for the cable to reach past ComponentBox's own interior.
NOTE this channel is off-center (at the arm's own position, not the pan axis), so it only
stays usably positioned relative to ComponentBox's interior across a LIMITED pan range
before rotating away from wherever the modules eventually get mounted inside it -- an
accepted tradeoff for keeping the pan pivot solid, not a full swivel connector. (The TILT
side doesn't have this limitation, per the "spigot on the stationary part" reasoning above
-- only pan does, since the pan pivot was deliberately kept solid instead of also being
hollow.)

SYMMETRIC ARMS, on request ("buat kedua lengan sama dimensinya"): both side arms share the
exact same `ARM_T` (thickness) and `ARM_W` (width) -- an earlier revision kept the left arm
slimmer since it never needed the down-channel's clearance margin, but unifying both to the
wider value the channel actually needs is what was asked for. The arms no longer need to
stay strictly within a square footprint (that constraint was specific to the earlier
square-box ComponentBox revision, "tidak keluar area kotak") -- now that ComponentBox is a
round turret, `TURRET_D` just needs to be big enough that the arms genuinely overlap/fuse
onto its own top face (checked via real FreeCAD bounding-box queries, not assumed, see
README), not that they stay fully inside its silhouette.

ARM_T (14mm, BOTH arms share this thickness, on request) was originally the RIGHT arm's own
wider value: the down-channel (10mm) needs to be fully enclosed with wall margin on both
faces, or it breaches through the arm's own front/back and becomes a visible stray hole --
which is what prompted an earlier cleanup pass (search "tidak terlihat" in the project
history / README). The left arm used to stay slimmer (6mm) since it never needed that
margin, but on request both arms are identical -- see "Symmetric arms" above.

Hinge hardware: M5 wing bolt + wing nut (pan pivot AND the left tilt pivot -- both stay
solid/structural), plus one M4 set-screw (right tilt pivot only, pressing on the
stationary spigot from CameraBody's rotating disc). Confirmed real, cheap, commonly
stocked (searched, not guessed): "WING NUT M4 M5 M6 M8 M10 ... MUR KUPING MUR KUPU KUPU"
on Tokopedia lists M4/M5 together. No bearings, no custom hollow bolts, no exotic
hardware -- the "spigot" is just a short printed shaft, part of ComponentBox's arm itself.

CAMERABODY IS NOW A SQUARE-CROSS-SECTION TUBE ("tabung persegi", on request): CASING_W and
CASING_H are equal (both driven up to CASING_W, since that's set by the real PCB width and
can't shrink) -- the body reads as a square tube extruded along its depth, not the flatter
rectangular box the first several revisions used. This is strictly MORE interior room than
the PCB/component stack needs (see _CASING_H_MIN), never less -- a styling choice, not a
fit requirement.

COMPONENTBOX IS NOW A ROUND ROTATING TURRET, on request ("rubah kotak diatas kamera ...
menjadi tabung bundar supaya dapat berputar"): this replaces the old MountPlate<->PanPlate
pan-pivot pair entirely. Explicitly confirmed with the user before building this (two
readings were possible -- just reshape ComponentBox into a cylinder while keeping it fixed,
or make ComponentBox itself the rotating part -- the user picked the latter: "ComponentBox
sendiri yang berputar").

New topology: a small FIXED `CeilingMount` plate (screws to wall/pole/ceiling bracket,
takes over MountPlate's old "fixed, generic mounting pattern" role) sits at the bottom of
the stack. `ComponentBox` is now a round, CLOSED cylinder (own top + bottom + side walls,
no separate lid needed anymore) that ROTATES on top of CeilingMount via a plain M5 wing
bolt + wing nut through both their centers (same friction-lock hardware pattern as every
other pivot in this design) -- and it's ComponentBox itself, not a separate PanPlate, that
the two side arms are now fused to. This merges what used to be THREE separate parts
(ComponentBox as a fixed electronics box + MountPlate as a fixed lid + PanPlate as the
rotating arm-holder) into TWO (CeilingMount fixed, ComponentBox rotating-with-arms).

Practical effect on the cable path: it used to be CameraBody -> arm -> PanPlate's own
down-channel -> a matching hole through MountPlate -> ComponentBox's interior (two
plate-hops). Now that the arms sit directly on ComponentBox's own top wall, the channel
only has to cross ONE wall (ComponentBox's own WALL_T-thick top) to reach the same
interior -- CeilingMount needs no cable hole at all anymore (reverted to a plain plate,
like the very first MountPlate design, since the electronics moved off of it).

`ComponentBox`'s pivot hole is on its BOTTOM face (mating with CeilingMount below it); the
arms are fused to its TOP face (same face they used to fuse to on PanPlate) -- these are
deliberately on OPPOSITE faces of the cylinder so the fixed pivot connection and the arm
attachment area can't physically collide with each other.

Assembly stack, all separate FreeCAD objects (not fused, so they can actually move
against each other once printed/assembled):
  CeilingMount -- NEW, FIXED, sits at the bottom of the stack (wherever this gets
                mounted). Plain M5 pan-pivot hole + 4 corner mounting holes, nothing else
                -- no cable routing through it anymore.
  ComponentBox -- NEW SHAPE: a round, closed cylindrical turret that ROTATES on top of
                CeilingMount (pan = left/right). Houses the buck converter + W5500 module
                eventually (no mounting designed for them yet, on request), and the two
                side arms are fused directly to its own top face, now IDENTICAL in
                thickness/width (on request -- left: M5 hole; right: the stationary spigot
                + bore + the hidden downward cable channel, now only one wall-hop deep,
                see above).
  CameraBody -- the camera shell (square-cross-section tube), PCB + SC3336 module inside.
                Left disc: solid, M5 hole. Right disc: same OD, with a bushing hole that
                the arm's stationary spigot inserts into -- CameraBody is what rotates
                here (tilt -- a SEPARATE axis from ComponentBox's own pan rotation).
  BackCover  -- separate, plugs CameraBody's open back. Remove only this for PCB access.

Run headlessly (same pattern as build_housing.py):
    cd camera-housing
    QT_QPA_PLATFORM=offscreen ~/Downloads/FreeCAD-1.1.3.AppImage --console <<'EOF'
    exec(open('camera_casing.py').read())
    EOF

ASSUMED values (search "ASSUMED" below): SC3336 board/lens dimensions and
COMPONENT_CLEARANCE are reused/defined here; PCB dimensions (CONFIRMED) come from
build_housing.py so there's exactly one place holding each number.
"""

import FreeCAD as App
import Part
import os
import sys

sys.path.insert(0, os.path.dirname(os.path.abspath(__file__)) if "__file__" in dir() else os.getcwd())
import build_housing as H  # reuse PCB (CONFIRMED) + SC3336/lens (ASSUMED) constants only

# ============================================================================
# ASSUMED / PLACEHOLDER -- verify against real hardware before printing.
# ============================================================================
COMPONENT_CLEARANCE = 18.0      # ASSUMED: tallest stack above the PCB (ESP32 Dev Board
                                 # Breakout on pin headers) -- measure the real populated
                                 # board and adjust.
CAM_MODULE_DEPTH = 15.0         # ASSUMED: front cavity depth for the SC3336 board + lens
                                 # holder, from the inside of the front wall.

# ============================================================================
# Design choices (freely adjustable)
# ============================================================================
WALL_T = 3.0                    # body shell thickness
MARGIN = 5.0                    # clearance around the PCB inside the body (same value
                                 # build_housing.py used for its flat Base, reused here)
FILLET_R = 2.5                  # edge rounding on the body's 4 vertical edges -- the
                                 # "minimalist" cue; must stay under WALL_T (3.0mm) since
                                 # BackCover's flat plate is only WALL_T thick, or the
                                 # fillet operation fails there
LENS_BEZEL_R = H.LENS_HOLE_D / 2.0 + 4.0   # recessed ring around the lens, minimalist
LENS_BEZEL_DEPTH = 1.5

CAM_BOARD_STANDOFF_H = 6.0      # SC3336 board standoffs, sticking out from the front wall
CAM_BOARD_STANDOFF_D = 4.0
CAM_BOARD_PILOT_D = 1.8          # self-tap pilot for the SC3336 board's own M2 screws

STANDOFF_HEX_AF = H.STANDOFF_HEX_AF    # PCB standoffs: same bought M3 hex spacers as
STANDOFF_H = H.STANDOFF_H              # build_housing.py used, just mounted inside this
STANDOFF_HOLE_D = H.STANDOFF_HOLE_D    # body's floor instead of on a flat Base

COVER_SKIRT_DEPTH = 6.0         # how far BackCover's skirt inserts into the open back
COVER_FIT_GAP = 0.3
COVER_SCREW_D = 2.5              # M3 self-tap pilot, BackCover to CameraBody
COVER_BACK_CLEARANCE = 2.0       # extra open-air gap between the PCB's back edge and
                                  # where BackCover's skirt begins -- MARGIN alone used to
                                  # be the only buffer there, which was thinner
                                  # (5mm) than the skirt itself (6mm), so the skirt
                                  # clipped into the PCB. Fixed by making CASING_DEPTH
                                  # explicitly account for the skirt + this extra margin.

HINGE_PIN_D = 5.3                # M5 wing bolt clearance (LEFT tilt pivot + pan pivot --
                                  # both stay solid/structural)
CABLE_HOLE_D = 10.0               # bore through the spigot -- the cable's actual path

HINGE_DISC_OD = 24.0               # BOTH pivots (left solid, right hollow) use this SAME
                                  # disc diameter now -- styled after DJI Osmo Pocket's
                                  # gimbal, where the arm and the module meet as matching
                                  # flush discs, not a small boss on one side and a big one
                                  # on the other. An earlier revision had the right boss
                                  # grow to ~22.4mm (RIGHT_BOSS_OD) just to contain its
                                  # bushing hole while the left stayed 16mm -- functionally
                                  # fine, but the size mismatch was exactly what looked like
                                  # an odd separate "big tube" bolted on, on request, fixed
                                  # by unifying both sides to one consistent disc size.
HINGE_DISC_LEN = 4.0               # short and flat, like Osmo Pocket's pivot housing --
                                  # replaces the old SIDE_BOSS_LEN-style long boss
PIVOT_GAP = 0.5                   # small clearance between the two discs, so they can
                                  # rotate against each other without rubbing

SPIGOT_OD = 16.0                   # RIGHT only: short alignment pin on the ARM's disc
                                  # (stationary), inserting into CameraBody's disc just far
                                  # enough for rotational support -- NOT a long tube
                                  # reaching all the way to the interior anymore; that job
                                  # is now the bore's alone (see below), decoupled from how
                                  # much solid spigot material there is
SPIGOT_LEN = 4.0                   # crosses PIVOT_GAP and reaches most of the way through
                                  # CameraBody's disc (HINGE_DISC_LEN) for real mechanical
                                  # engagement, without needing to reach the wall/interior
BUSHING_CLEARANCE = 0.4           # diameter clearance, CameraBody's hole vs. the spigot's
                                  # OD -- loose enough to actually rotate once printed
SETSCREW_PILOT_D = 3.3            # M4 self-tap pilot, pressing onto the spigot for
                                  # friction-lock (drilled through CameraBody's rotating
                                  # disc, from outside -- see build_camera_body())
BORE_ENGAGE = 1.0                 # how far the RIGHT cable bore reaches past the inner
                                  # wall face into CameraBody's cavity (kept short --
                                  # checked, not assumed, that it still clears the PCB;
                                  # see README). This is the bore's own reach, independent
                                  # of the spigot's shorter SPIGOT_LEN -- past the spigot's
                                  # tip, the cable just continues through open (already
                                  # cut) hole, no solid material needed there.

DOWN_CHANNEL_D = 10.0             # the hidden channel inside the arm + ComponentBox's own
                                  # top wall (from the spigot's bore down into the turret's
                                  # interior) -- same diameter as CABLE_HOLE_D, named
                                  # separately since it's a distinct feature (not coaxial
                                  # with a pivot)

# CASING_W needed below (TURRET_D depends on it) -- pulled up ahead of the rest of the
# "body dimensions" block further down, which still uses it (not duplicated)
CASING_W = H.PCB_W + 2 * MARGIN + 2 * WALL_T

ARM_T = 14.0                      # BOTH side arms use this SAME thickness (X direction),
                                  # on request ("buat kedua lengan sama dimensinya") -- an
                                  # earlier revision kept the left arm slim (6mm, just
                                  # enough for its M5 hole) and only the right arm wide
                                  # (14mm, needed so DOWN_CHANNEL_D (10mm) stays fully
                                  # enclosed with wall margin on both faces, or it breaches
                                  # through as a visible stray hole); unifying both to the
                                  # right arm's wider value is what the channel needs
ARM_DISC_COVER = 2.0              # how far the arm posts must exceed HINGE_DISC_OD's own
                                  # radius/diameter, so the post visibly COVERS the hinge
                                  # disc instead of the disc overhanging past a narrower
                                  # post -- an earlier revision made the arm narrower than
                                  # the disc on purpose (Osmo-Pocket "slim arm" look), but
                                  # that made the disc look bigger than its own support, on
                                  # request, fixed by tying the post's size to the disc's
ARM_W = HINGE_DISC_OD + 2 * ARM_DISC_COVER   # width (Y direction) now exceeds the disc's
                                              # own diameter on both sides, not the other
                                              # way around -- same for both arms
ARM_TOP_MARGIN = HINGE_DISC_OD / 2.0 + ARM_DISC_COVER   # reaches past the disc's own top
                                                        # edge too (disc's radius + margin),
                                                        # not just partway up it

# ---- ComponentBox: round ROTATING turret, on request ("rubah kotak ... menjadi tabung
# bundar supaya dapat berputar") -- houses the buck converter + W5500 Ethernet module
# eventually (no mounting designed for them yet, "tidak perlu dibuat dudukan untuk
# sekarang"), AND now carries the two side arms directly (see module docstring for the
# full topology change). TURRET_D is sized off REAL searched module dimensions (not
# guessed): a common LM2596 buck module is 43.2 x 21 x 14mm, and a W5500 module with an
# RJ45 jack is ~55 x 28 x 15mm -- both fit comfortably within a 110mm-diameter circle side
# by side, with real margin left over (checked, not assumed -- see README). TURRET_H
# clears the taller module (15mm) with real room for wiring above it.
TURRET_D = 110.0                  # ASSUMED placeholder, same reasoning as the old
                                  # BOX_SIZE/PLATE_SIZE -- exact component placement inside
                                  # still isn't designed. Unlike the old square box, the
                                  # arms are NOT required to stay fully within this
                                  # footprint anymore (see "Symmetric arms" in the module
                                  # docstring) -- they just need to genuinely overlap/fuse
                                  # onto the turret's own top face, checked below.
TURRET_H = 25.0                   # same value/reasoning as the old BOX_H
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

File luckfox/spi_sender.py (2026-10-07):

#!/usr/bin/env python3
"""Runs on LuckFox: read raw NV12 frames (no header, back-to-back -- see
../backend/ and the pi4-camera-stream-noencode tool that produces them),
split each frame into kVideoStreamsPerNode vertical strips (one per parking
lane covered by this node's camera), downsample each strip to the chain's
per-stream size, encode, and push all of them to this node's paired
ESP32-S3 over SPI (Linux spidev, master) as the local leg of
file -> LuckFox -> SPI -> ESP32 -> RPi4.

Splitting: the source frame is SRC_W wide; stream N gets the vertical slice
[N*STRIP_W, (N+1)*STRIP_W) at full SRC_H, independently downsampled to
DST_W x DST_H. All 3 streams come from the same captured frame (same
moment in time, same seq number per frame) -- this used to be a round-robin
placeholder that gave every stream the *same*, full, undivided frame once
every 3rd capture (1/3 the real frame rate each); that never actually
split anything spatially, just multiplexed identical whole frames across
3 stream_ids.

Counterpart: src/ESP32-S3-RAP/main/luckfox_spi.{h,cpp} (SPI *slave* there --
Linux spidev is master-only, and the ESP32 side already uses spi_master.h
for the Gateway's W5500, so this stays master / ESP32 stays slave to
avoid two masters on one bus).

Encoding note: video frames are hardware-encoded H.264 (see
rkvenc_subprocess.py -- RV1103's own VENC block via a persistent
rk_mpi_venc_test subprocess, since this LuckFox image's Pillow build has
no JPEG encoder at all, and PNG -- the original placeholder -- is a poor
fit for a stream of mostly-static frames: real hardware testing measured
~366KB/frame PNG vs ~21KB for an H.264 I-frame and as little as ~20-40
bytes for an unchanged P-frame, since PNG has no notion of "this frame is
almost identical to the last one" the way H.264's inter-frame prediction
does. One encoder per lane, kept resident for the process's lifetime (see
main()) -- same reasoning as detect_car()/detect_plate()'s NPU models
staying loaded rather than reloading per frame. Plate crops (rare, one-off
stills, not a stream) stay PNG -- H.264's inter-frame compression has
nothing to exploit for a single unrelated image, and PNG's lossless
encoding matters more there than for a continuous low-motion video feed.

Also runs each lane's parked-car detection (see parking_detector.py) against
the same downsampled snapshot already computed for its video stream --
motion detection gates a parked-car occupancy check, which gates plate
cropping, so the expensive stages only run when something's actually
changed in frame. Occupancy readings go to the ESP32 as their own SPI
message (kMsgStatus); plate crops (only sent once per new parking event)
ride the same image path as video, on a reserved stream_id per lane.

Requires SPI0 M0 enabled first (not persistent across reboots by default):
    source /usr/bin/luckfox-config noop
    luckfox_config_init
    luckfox_spi_app 1 0 0 1 1 20000000

Also requires models/yolov5n.rknn and models/plate_detector.rknn (this
repo) pushed to RKNN_MODEL_PATH/PLATE_MODEL_PATH below (default
/root/yolov5n.rknn, /root/plate_detector.rknn) for the RKNN car-detection
and plate-detection steps -- see those constants and detect_car()'s/
detect_plate()'s docstrings for what they're for. Both stay loaded on the
NPU together (see _get_plate_model()).
"""
import argparse
import gc
import struct
import sys
import time

import spidev
from PIL import Image

from parking_detector import LaneDetector
from rkvenc_subprocess import H264Encoder

SRC_W, SRC_H = 1920, 1080
Y_SIZE = SRC_W * SRC_H
FRAME_SIZE = Y_SIZE + Y_SIZE // 2

DST_W, DST_H = 600, 400  # kVideoStreamsPerNode streams, this size each (config.h)
STREAMS_PER_NODE = 3
STRIP_W = SRC_W // STREAMS_PER_NODE  # 640px-wide vertical slice per stream
# Plate crops ride the video path on a reserved stream_id per lane, above
# the real video streams -- must match config.h's kPlateStreamBase.
PLATE_STREAM_BASE = STREAMS_PER_NODE

# Must match config.h's kLuckfoxSpiChunkBytes exactly -- both ends assume
# every SPI transaction is this many bytes.
CHUNK_BYTES = 4000

MAGIC = 0x52415046  # "RAPF", must match luckfox_spi.cpp's kMagic
MSG_VIDEO = 0  # video frame or plate crop image -- must match luckfox_spi.cpp's kMsgVideo
MSG_STATUS = 1  # lane occupancy reading -- must match luckfox_spi.cpp's kMsgStatus
# WireHeader: uint32 magic, uint8 msg_type, uint8 stream_id, uint16 seq,
# uint32 data_len (little-endian, packed -- matches the
# __attribute__((packed)) struct on the ESP32 side; both are little-endian
# cores so this lines up as-is).
HEADER_FMT = "<IBBHI"

# Must match config.h's kMaxPlateLen exactly -- the plate field in
# LaneStatusWire (luckfox_spi.cpp) is this many chars + a null terminator.
MAX_PLATE_LEN = 11
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

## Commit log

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2026-08-23 Add LuckFox RAP Shield KiCad project (was: generic ESP32 handheld camera template)
    The imported KiCad project was a clone of an unrelated DIY handheld ESP32
    camera device (TFT screen, D-pad buttons, SD card, RTC, LiPo battery
    boost) -- none of which were ever ParkingVision requirements. Reworked it
    into an actual parking-lot node shield:
    - Removed: TFT, MicroSD, RTC, PowerBoost 500 (LiPo), I2C level shifter,
    ArduCam OV2640, all buttons/switches, and their now-orphaned wiring.
    - Renamed ESP32_Dev_Board_Breakout -> ESP32-S3-DevKitC-1 (the old symbol
    was modeled on a classic 38-pin ESP32 with the wrong GPIO map for S3;
    new symbol only claims the pins this design actually uses).
    - Etherne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
    [LuckFox RAP Shield.kicad_pcb, LuckFox RAP Shield.kicad_sch]
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2026-08-31 Wire up LuckFox RAP Shield schematic manually in KiCad, remove onboard input-protection module
    Manually drew the real wire connections in KiCad's schematic editor (the
    previous commit only placed components + used global labels for
    multi-endpoint power nets, per the connection table/wiring diagram --
    this fills in the rest by hand in the GUI instead of scripted coordinates).
    Also removed J2 (Input_Protection_DCJack_12V) -- reverse-polarity diode +
    PTC fuse + TVS + DC jack now live on a separate external module instead of
    on this shield, per a hardware decision to keep that circuitry off-board.
    U3 (MP1584EN buck) is still present for now, fed by new +12V/-12V power
    flags -- a follow-up commi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
    [LuckFox RAP Shield.kicad_sch]
2026-08-31 Remove onboard buck converter (U3) from RAP Shield schematic
    Power regulation (12V->5V buck) and reverse-polarity protection now
    live on an external module ahead of the shield, not on the board
    itself. U3 (MP1584EN) and its +12V/-12V power-flag symbols are
    removed; a new 2-pin J2 connector (External_5V_Input_from_Buck_Module)
    takes the shield's 5V input, positioned so its pins land exactly on
    U3's old output-pin coordinates and reuse the existing downstream
    wiring unchanged.
    [LuckFox RAP Shield.kicad_sch]
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2026-08-31 Rebuild J1 as real LuckFox Pico Mini 22-pin header, fix broken SPI wiring
    J1 was a placeholder 9-pin symbolic connector for a cable link. LuckFox
    is actually a Pi-HAT-style module plugging into a 2x11, 2.54mm-pitch
    header (17.78mm row spacing, 21.00x28.14mm outline, per LuckFox's
    official mechanical drawing). Rebuilt J1's schematic symbol with all
    22 real pins/names, and added a matching custom footprint
    (libs/footprints.pretty/LuckFox_Pico_Mini.kicad_mod) since no stock
    KiCad footprint matches this pitch/spacing.
    While rebuilding J1's wiring, traced the full netlist from the raw
    wires/labels (not the wiring diagram) and found the existing manual
    KiCad wiring was substantially broken: W5500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
    [LuckFox RAP Shield.kicad_sch]
2026-08-31 Fix U2 wiring: account for its (mirror y) placement flag
    U2's instance has a mirror-y flag (set from before this session) that
    I missed when computing its pin positions -- both when generating the
    SPI-ETH wires/power-rail labels and when validating them, so the
    validation was checking its own wrong assumption and passed anyway.
    Net effect: CS/SCK/MOSI/MISO/INT are actually on U2's west side and
    VCC_3V3/GND/RST on the east, the opposite of what was wired, which is
    exactly what was visible in KiCad as wires landing away from the pins.
    Recomputed U2's true pin positions with the mirror transform applied
    and rerouted the 5 SPI-ETH wires and 3 power-rail label stubs to
    match. Re-verified with a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
    [LuckFox RAP Shield.kicad_sch]
2026-08-31 Lengthen global-label stubs and fix a masked U2 pin-position bug
    Global label stubs were only 2.54mm (same as the pin length itself),
    so label hexagons sat right on top of neighboring pins' name text --
    visually indistinguishable from a real disconnection, which is what
    was showing up in KiCad. Lengthened all 12 stubs to 15mm.
    While doing this, found the U2 power-rail wires (VCC_3V3/GND/RST)
    were anchored 2.54mm short of the true pin tip -- a manual arithmetic
    slip in the earlier mirror fix (forgot to add the pin's own length
    after mirroring) that happened to still connect only because the old
    short stub's far end coincidentally landed exactly on the real pin.
    Extending the stub from that w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
    [LuckFox RAP Shield.kicad_sch]
2026-09-01 Manual wiring fixes in KiCad; switch J1 to castellated cutout mount
    Schematic: incorporates your manual fixes in the KiCad GUI (component
    repositioning, mirror/rotation adjustments) that brought ERC down from
    141 to 14 messages, mostly remaining "not driven" warnings (expected
    for global-label-based power rails without an explicit PWR_FLAG, not
    real breaks). One genuine wire_dangling remains on the DATA_RDY-ish
    net -- left for direct fixup in the GUI since positions were hand-
    adjusted and no longer match a clean re-derivable formula.
    Footprint: LuckFox_Pico_Mini.kicad_mod rebuilt from a through-hole
    socket into a board-cutout + edge-castellation mount. LuckFox nests
    underneath the shield (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
    [LuckFox RAP Shield.kicad_sch]
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2026-09-01 Center LuckFox castellated cutout under ESP32-S3's board center
    Computed from the corrected ESP32 footprint's true outline (27.94 x
    63.39mm, center at local (13.97, 31.695)) and the LuckFox cutout's own
    local center (10.5, 14.07), against B2's current placed position
    (121.425, 83.425). J1 moved from (149.775, 84.025) to (124.895,
    101.05) so the cutout center lands exactly on B2's board center.
    Note: B2's footprint data cached in this file is stale (still the old
    38-pad/25.9x48.5mm geometry from before the ESP32 footprint rebuild)
    -- needs Update PCB from Schematic (or Update Footprint on B2) to pick
    up the corrected 44-pin/27.94x63.39mm geometry before the centering is
    visible correctly in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
    [LuckFox RAP Shield.kicad_pcb]
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2026-09-01 Re-center J1 for the corrected (margin-free) ESP32 board length
    B2's board center moved from local (13.97, 31.695) to (13.97, 26.67)
    now that the footprint's true length is 53.34mm, not 63.39mm. Also
    picked up B2's and J1's latest positions from your own KiCad edits
    (both had moved since the last commit). J1 recentered at (124.8,
    94.52) using the current B2 position (121.33, 81.92).
    [LuckFox RAP Shield.kicad_pcb]
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2026-09-01 Re-center J1 for the margin-corrected ESP32 footprint
    B2's board center shifted to local (13.97, 27.52) with the added
    0.85mm edge margin. J1 recentered at (124.8, 95.37) using B2's current
    position (121.33, 81.92); also picked up that J1 had moved again in
    your own session since the last commit.
    [LuckFox RAP Shield.kicad_pcb]
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2026-09-01 Re-center J1 for the corrected LuckFox footprint dimensions
    J1 local center shifted to (10.5, 13.4) with the new 21x26.8mm body.
    Re-centered at (124.8, 96.04) using B2's current position; also
    picked up that J1 had moved again in your own session.
    [LuckFox RAP Shield.kicad_pcb]
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2026-09-01 Redraw all wiring to match current component positions/rotations
    All 47 wires and 14 no_connect flags were stale, drawn against B2/J1/
    J2/U2 positions from before several rounds of manual mirror/rotate/
    move edits in the KiCad GUI. Confirmed with a brute-force check (every
    mirror hypothesis, every component, against real wire endpoints):
    zero matches anywhere, including U2's simple rotate-180-no-mirror
    case -- not a transform-formula bug, the wires just didn't follow the
    moves.
    Recomputed every pin's true current absolute position (mirror- and
    rotation-aware) and every pin's true exit direction, then redrew all
    14 nets (SPI0, SPI-ETH, +5V_RAIL, +3V3_RAIL, GND) and all 13
    intentionally-unuse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
    [LuckFox RAP Shield.kicad_sch]
2026-09-01 Fix mirror=x transform: negate X, not Y (was backwards)
    Fresh ERC from the user caught this: every wire near B2/J1/J2 (all
    mirror=x) was reported wire_dangling, while U2 (no mirror, just
    rotation) had no such issue. Cross-checked one specific case exactly:
    the wire I drew for J1 pin 6 ends at (40.64, 39.37) -- byte-identical
    to one of ERC's reported dangling wire coordinates, converted from
    mils. That's not a coincidence; it means my mirror=x formula (negate
    Y, keep X) was wrong.
    My earlier "validation" of this formula was circular: both the wire
    generator and my checker used the same formula, so they always agreed
    with each other regardless of whether either matched KiCad's actual
    behavior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
    [LuckFox RAP Shield.kicad_sch]
2026-09-01 Discover the mirror flag doesn't affect pin position at all; rewire
    The negate-X "fix" last commit still produced the same 42 ERC errors,
    just shuffled onto different pins -- proof the axis-swap theory was
    also wrong, not just imprecise.
    Found clean, exact ground truth this time: ERC's endpoint_off_grid
    warnings include literal "Symbol REF Pin N" root coordinates (no
    length added, so no tip-vs-root ambiguity to misread). Two independent
    pins (J1 Pin 12, B2 Pin 10) both match their position computed with
    the mirror flag ignored entirely -- only the symbol's own rotation
    angle matters. Both matched to the exact hundredth of a mm; no mirror
    hypothesis (negate X, negate Y, either axis) matched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
    [LuckFox RAP Shield.kicad_sch]
2026-09-01 Rediscover and fix the real bug: Y-axis was never flipped for local pin coords
    Root cause of the persistent 42 ERC errors was never the mirror flag -- it
    was that every pin-position formula used this session omitted a required
    Y-axis sign flip between symbol-library space (Y-up) and sheet space
    (Y-down), even for components at rotation 0. Validated the corrected
    formula (ax = cx + lx*cosT + ly*sinT, ay = cy - lx*sinT - ly*cosT) against
    17 independent ERC-reported ground-truth pin positions, all exact matches.
    Full rewire of all 47 wires, 12 global labels, and 14 no-connects from
    scratch using the corrected pin coordinates.
    [LuckFox RAP Shield.kicad_sch]
2026-09-01 Fix double-extension bug: pin (at x y) is already the connection point
    The real bug (unrelated to mirror or rotation direction): a KiCad pin's
    (at lx ly angle) coordinate already IS the electrical connection tip --
    length only draws the visual stub line back toward the body, it does not
    push the connection point further out. The previous rewrite was adding
    length*(cos,sin) on top of the already-correct tip, overshooting every
    pin by 2.54mm and leaving every wire touching empty space. Removed the
    length extension; wires now terminate exactly at each pin's (at x y).
    [LuckFox RAP Shield.kicad_sch]
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2026-09-01 Replace hand-written PWR_FLAG symbol with exact copy from KiCad's power library
    Silences the lib_symbol_mismatch warnings -- the embedded copy now matches
    /usr/share/kicad/symbols/power.kicad_sym byte-for-byte (power global flag,
    pin_numbers/pin_names hide flags, Description and ki_keywords properties
    that the hand-written version was missing).
    [LuckFox RAP Shield.kicad_sch]
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2026-09-01 Draw main board outline and bump ESP32 silkscreen text to the min height
    Board outline: a rectangle with a notch cut into the bottom edge, exactly
    matching J1's LuckFox cutout mouth (124.85,136.24)-(146.15,136.24), so the
    cutout's 3 walls merge into one closed Edge.Cuts loop with the LuckFox
    module's USB-C end poking through the notch. Everywhere else the edge
    sits at Y=140, clear of B2 and J2's nearest pads by several mm -- fixes
    the invalid_outline/copper_edge_clearance DRC errors.
    ESP32 footprint: all 44 pin-label texts were 0.7mm tall, under the
    board's 0.8mm silk text height rule; bumped to 0.8mm/0.12mm thickness.
    [LuckFox RAP Shield.kicad_pcb]
2026-09-01 Fix self-intersecting board outline: remove redundant notch-top segment
    The notch I drew to meet J1's cutout mouth duplicated the path J1's own
    3 wall segments already provide (right wall - top wall - left wall),
    creating a 3-way T-junction at each mouth corner instead of the 2-edges-
    per-vertex a simple closed polygon needs. Removed my direct
    (146.15,136.24)-(124.85,136.24) segment so the outline now detours
    through J1's own U-shape as its one and only path between the two
    connector points.
    [LuckFox RAP Shield.kicad_pcb]
2026-09-01 Add castellation DRC exception for J1; sync B2's embedded font sizes
    Custom rule (.kicad_dru) sets edge_clearance to 0 for J1 specifically --
    its 22 pads are intentionally centered on the board edge for lap-solder
    castellation, which the default copper-to-edge rule can't distinguish
    from a real violation.
    The 0.7mm->0.8mm text height fix committed earlier only touched the
    library file; the PCB keeps its own baked-in copy of the footprint from
    Update-PCB-from-Schematic, so the same 8 labels (RST, GPIO44, GPIO41,
    GPIO40, GPIO38, GPIO48, GPIO47, GPIO20) were still 0.7mm there. Patched
    directly.
    [LuckFox RAP Shield.kicad_pcb]
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2026-09-01 Fix RST rotation and abbreviate 4 stray GPIOxx labels on B2 (PCB copy)
    RST was the only silkscreen label rotated 90deg while every sibling
    label (5V, EN, GND, GPIO4, ...) sits horizontal -- an inconsistency, not
    intentional. When rotated, RST's 3-character box extends vertically and
    swallows the tightly-packed neighboring unused-pin labels "34"/"39"
    (only ~1.2-1.3mm away). Rotating it back to 0 matches every other label
    and clears the overlap.
    GPIO40/41/47/48 were the only unused-pin labels still using the full
    "GPIOxx" name; every other unused pin on this footprint was already
    abbreviated to a bare number (e.g. "34", "39"). At 6 characters the full
    name is too long for the 2.54mm row pitch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
    [LuckFox RAP Shield.kicad_pcb]
2026-09-01 Nudge J1's pin-1/pin-11 silkscreen labels away from B2's pads
    Both labels sat only ~1mm from a B2 pad center (well inside typical
    silk-to-copper clearance), triggering silk_over_copper. Shifted each
    ~1.5mm further out (away from B2, still 6mm+ clear of the outer board
    edge) to give real breathing room.
    [LuckFox RAP Shield.kicad_pcb]
2026-09-01 Expose both USB-C connectors, add 4 M3 mounting holes, relocate J2
    Board outline: widened (X 115-158, Y 75-137) and the bottom edge pulled
    up from Y=140 to Y=137 -- flush with B2's own real board edge (137.02)
    instead of overhanging 3mm past it -- so neither the ESP32-S3's USB-C
    (at B2's bottom edge) nor the LuckFox's USB-C (through J1's cutout
    mouth, unchanged at Y=136.24) has shield material in front of it.
    J2 (5V input header) relocated from (119,133.46) to (119,95): its old
    spot was inside the zone the new flush edge passes through, leaving
    only ~1.5mm copper clearance. Moved to open space above U2 instead
    (9mm+ clear on every side). No nets/pins changed, position only.
    Added 4 Mountin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
    [LuckFox RAP Shield.kicad_pcb]
2026-09-01 Widen left edge and move H1/H3 mounting holes clear of B2
    H3 was only ~0.4mm from B2's courtyard (2.13mm center-to-box gap minus
    the hole's own 1.7mm courtyard radius) -- too tight for an M3 screw/
    washer in practice. Widened the board's left edge 115->113mm and moved
    H1/H3 from X=119 to X=117, giving both holes a comfortable ~4mm clear
    of B2 while keeping the same 4mm margin from the board's own edge.
    [LuckFox RAP Shield.kicad_pcb]
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2026-09-01 Hide mounting hole Value text too (same edge-overhang risk as Reference)
    Value sits 4.15mm below the hole center -- for H3/H4 (Y=134, 3mm above
    the bottom edge at Y=137) that pushes it to Y=138.15, past the edge,
    mirroring the Reference-label issue just fixed for H1/H2 on the other
    side. Hidden on all 4 for consistency.
    [LuckFox RAP Shield.kicad_pcb]
2026-09-01 Push normal bottom edge 137.0 -> 137.6mm: B2's own pad copper reached it
    B2's bottom-row THT pads are 1.7mm square centered at Y=136.17, so their
    real copper edge is at 136.17+0.85=137.02mm -- 0.02mm past the Y=137
    edge I'd picked using only the pad center, not its actual size. 137.6mm
    gives 0.58mm clearance past the pad's true copper edge. J1's notch mouth
    is untouched (still 136.24, matching the cutout) since that's governed
    by the separate castellation DRC exception, not this rule.
    [LuckFox RAP Shield.kicad_pcb]
2026-09-01 Nudge J1's pin-11 label up 0.34mm to clear the raised bottom edge
    Moving it away from B2's pad earlier pushed it down to Y=137.64, which
    became too close once the bottom edge moved to Y=137.6 in this commit
    sequence. Pulled back up to Y=137.3 (local 27.16), clear of both.
    [LuckFox RAP Shield.kicad_pcb]
2026-09-01 Push J1's pin-11 label further from the bottom edge (0.3mm was too tight)
    Previous nudge to Y=137.3 left only 0.3mm to the Y=137.6 edge, still
    flagged. Moved to Y=136.9 (local 26.76) for 0.7mm clearance.
    [LuckFox RAP Shield.kicad_pcb]
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2026-09-01 Fix power net traces reaching J1: add vias, J1's pads are B.Cu-only SMD
    The GND->J1.2, GND->J1.21, and +5V_RAIL->J1.1 segments ran all the way
    to the pad on F.Cu, but J1's castellated pads only exist on B.Cu -- an
    F.Cu trace can't physically land on them. Split each into an F.Cu run
    up to a via, then a short B.Cu stub from the via into the pad.
    [LuckFox RAP Shield.kicad_pcb]
2026-09-01 Rewrite power net routing to fix real short-circuits from the first attempt
    Previous routing had the GND trunk running straight through U2's entire
    pin column (not just its GND pin), vias placed too close to neighboring
    pads, and +5V_RAIL/GND crossing each other near B2.1/B2.3/J1.1/J1.2 --
    those four pads are so tightly pitched that +5V's target (J1.1) and
    GND's target (J1.2) are effectively swapped relative to their source
    pads on B2, forcing the two nets to cross physically.
    New approach, every clearance checked programmatically before writing:
    - +3V3_RAIL: B.Cu, dedicated X=114 lane, never shares space with anything.
    - +5V_RAIL: F.Cu trunk to B2.1, then continues directly on B.Cu (THT pa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
    [LuckFox RAP Shield.kicad_pcb]
2026-09-01 Rewrite power routing again: fix track width, via drill, and full-pad checks
    Third pass. This time verified programmatically against ALL 80 real pads
    (including B2's 28 unused ones and mounting holes, which the previous
    pass never checked) plus proper net-aware exclusion (a trace may freely
    touch its own net's pad; only different-net proximity counts).
    Fixes: bumped every trace to >=0.2mm (board minimum; 0.15mm had been
    silently under the rule), via drills to 0.3mm minimum, routed +5V_RAIL's
    approach to B2.1 around mounting hole H3's keepout, adjusted the J1.2/
    J1.21 detour heights to clear B2's unused pads at Y=131.09, and moved
    +5V_RAIL's trunk/crossing (now partly via a short B.Cu hop) s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
    [LuckFox RAP Shield.kicad_pcb]
2026-09-01 Fix via size (min 0.4mm dia) and annular width, resolve last via clearance
    Vias were 0.3mm diameter with 0.3mm drill -- below the 0.4mm minimum
    diameter rule and leaving zero annular ring (size == drill). Bumped to
    0.6mm/0.3mm drill. That changed the via radius enough to newly violate
    clearance against a nearby GND track, so moved +5V_RAIL's B.Cu crossing
    point from X=120.5 to X=120.75 -- verified offline this sits with >=0.2mm
    clearance from both flanking GND branches (X=120 and X=121.5).
    [LuckFox RAP Shield.kicad_pcb]
2026-09-01 Fix remaining via clearances using accurate rectangular pad geometry
    Discovered my clearance checker was approximating every pad as a circle
    of radius max(w,h)/2 -- optimistic for elongated (non-square) pads like
    J1's 1.8x1.4 SMD pads, since a true rectangle's corner sits further out
    than that circle in diagonal directions. Rewrote the checker to use
    real point-to-rotated-rect distance for every pad.
    Simplified +5V_RAIL to a single via (was two): since B2.1 is a THT pad
    reachable from B.Cu directly, there's no need to hop back to F.Cu after
    crossing GND's row -- it can stay on B.Cu all the way through to J1.1.
    This also removed the now-unneeded via-hop GND had for crossing +5V's
    old trunk p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
    [LuckFox RAP Shield.kicad_pcb]
2026-09-02 Route SPI0 bus (MOSI, MISO, SCK, CS) between B2 and J1
    Same tight-corridor problem as the power nets, worse: 4 signals need to
    cross from B2's densely-packed pin column to J1's, and MOSI/MISO swap
    relative order (B2: MOSI,MISO,SCK,CS top-to-bottom; J1: MISO,MOSI,SCK,CS)
    so they physically cross.
    Each signal crosses B2's column at a gap between unrelated B2 pins
    (never at its own target Y, which usually coincides with a *different*
    B2 signal pin only ~0.07mm away) using an F.Cu lane -> via -> B.Cu
    crossing, then a short vertical adjust inside the B2/J1 gap to its
    target Y -- each signal's adjustment range doesn't overlap another's,
    so they don't need to coexist in the 0.65mm gap simultaneous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
    [LuckFox RAP Shield.kicad_pcb]
2026-09-02 Route SPI-ETH bus (INT_ETH, CS_ETH, MOSI_ETH, SCK_ETH, MISO_ETH) between B2 and U2
    INT_ETH (crosses all 4 other signals, like MOSI did in SPI0) takes an
    F.Cu detour east of B2's column, then re-crosses west through the
    B2 pin12/pin13 gap before approaching U2.8 from the north.
    CS_ETH needed a multi-stage B.Cu dodge: its B2 source Y (120.93)
    nearly coincides with SCK_ETH's U2 target Y (120.96), so it drops to
    an intermediate safe Y (120.5) before crossing SCK_ETH's lane, then
    drops again to its true target Y west of SPI0's sck-3 B.Cu jog.
    SCK_ETH and MISO_ETH sit on B.Cu lanes (X=120.9, X=120.3) that never
    reach U2's column at their own source Y, avoiding the same class of
    conflict. MOSI_ET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
    [LuckFox RAP Shield.kicad_pcb]
2026-09-02 Fix SPI-ETH CS_ETH/SCK_ETH clearance against SPI0's own layer-transition vias
    Real DRC caught 2 clearance violations that my offline simulation
    missed: SPI0's SCK and CS nets each have a via where their route
    transitions from F.Cu to B.Cu (at (120.825,119.66) and
    (121.45,122.2) respectively) that I hadn't included as obstacles
    when designing the SPI-ETH bus.
    - CS_ETH now takes a 3-stage dodge: a short notch down to Y=120.4
    clears SCK_ETH's lane start (Y=120.96) by 0.31mm, then a narrow
    but positive corridor at X=120.19 (0.635mm from the SCK via,
    0.34mm from U2's pad edge) carries it down to the target Y, west
    of SPI0's sck-3 B.Cu track.
    - SCK_ETH's lane moved from X=120.9 to X=120.8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
    [LuckFox RAP Shield.kicad_pcb]
2026-09-02 Route DATA_RDY and SLAVE_RDY_OUT, completing all 14 nets
    DATA_RDY (B2.14 <-> J1.10): both endpoints' Y (100.61 and 113.38)
    each nearly coincide with an unrelated pin on the OTHER component
    (J1.11 at 110.84 sits directly in the straight-line path; B2 has an
    unused pad at 113.31, 0.07mm from the target). Routed via a west-side
    B.Cu detour that only enters the tight B2-J1 corridor after clearing
    J1.11's Y, avoiding both conflicts.
    SLAVE_RDY_OUT (B2.15 <-> J1.18): the long run from B2's left column
    to J1's right column (X=146) travels up and over on F.Cu -- clear of
    J1's pads entirely since they're B.Cu-only SMD -- staying north of
    the B2/U2/J1 congestion and south of GND's full-width trunk (gn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
    [LuckFox RAP Shield.kicad_pcb]
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
